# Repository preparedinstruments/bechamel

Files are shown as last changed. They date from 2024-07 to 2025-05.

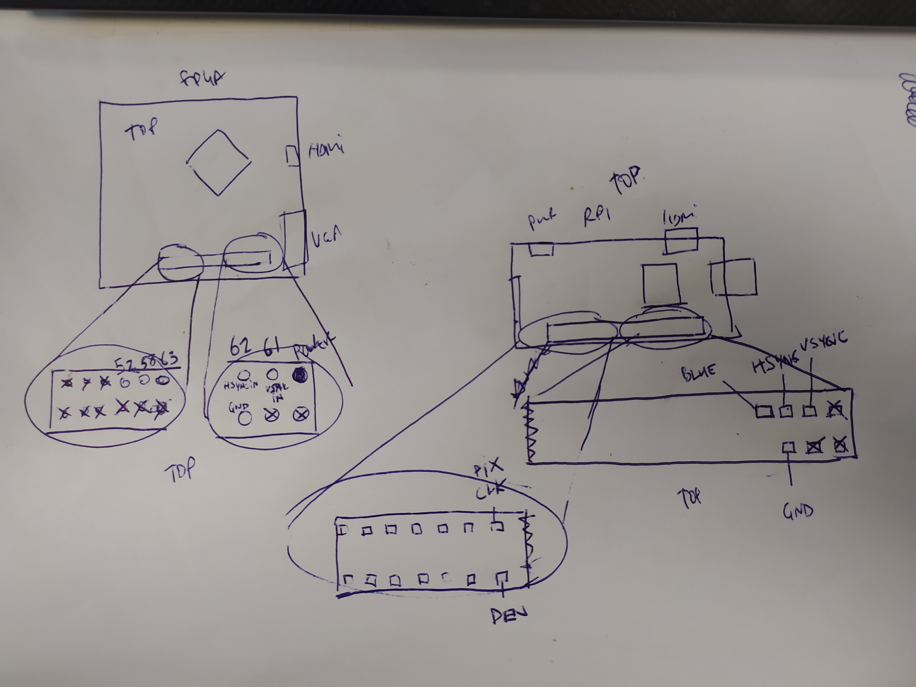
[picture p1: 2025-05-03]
verilog/SRAM FPGA RPI PASS THRU/IMG_20241218_101829.jpg

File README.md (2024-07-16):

bechamel_logo_Plan de travail 1

# Lo-Fi FPGA Video Art Board

A Lattice iCE40HX1K-based FPGA developement board for lo-fi, live-playable video experiments ranging from the gnarly/migraine-inducing all the way to the accidentally enjoyable.



 

|                          |                          |
:-------------------------:|:-------------------------:
  | IMG_3808-1024x683

# Features :

**WARNING: This video may potentially trigger seizures for people with photosensitive epilepsy. Viewer discretion is advised.**

https://github.com/user-attachments/assets/2b71dbfc-7b5e-4651-8198-416c93c0dd36

- 640x480 60Hz HDMI and VGA out, takes raspberry pi video in in DPI mode (https://pinout.xyz/pinout/dpi)
- 9-key mechanical button interface on a hand-solderable, low-cost, single-board design
- 100MHz clock and a 256K x 8 bit external SRAM for screen buffer(s)
- Connections for raspberry pi flash programming

# PCB files

[KiCAD and Eagle PCBs](https://github.com/preparedinstruments/bechamel/tree/main/PCB)

forgithub

# BOM :

[Excel BOM Mouser / Digikey ](https://github.com/preparedinstruments/bechamel/tree/main/BOM)

- 9x Mechanical keyboard keys
- 1x FPGA iCE40HX1K-TQ144
- 1x 100MHz clock oscillator
- 1x SRAM 2Mb 256Kx8
- 1x Flash N25Q032A13ESC40F
- 1x USB-C SMD 6 pin connector
- 1x 3.3V reg TLV73333PDBVT 
- 1x 1.2V reg TLV73312PDBVT
- 1x PFET
- 1x Resettable Fuse
- 1x D-SUB 15 connector
- 1x HDMI Connector 
- 50x 0.1µF capacitor 0805
- 50x  10kΩ, 1.8kΩ, 1kΩ, 470Ω, 270Ω, 120Ω resistors 0805
- 5x LEDs 0805
- 2x Dual-row headers

optional extras : (1x Raspberry Pi Zero, 1x Micro SD holder, 1x 10kΩ potentiometers)

# HDL files

[Verilog and Pin constraints files ](https://github.com/preparedinstruments/bechamel/tree/main/verilog)

To synthesize files :

[Yoysis Open-source Toolchain ](https://github.com/YosysHQ/yosys)



...or, request an iCEcube2 licence from Lattice :

[iCEcube2 Toolchain](https://www.latticesemi.com/iCEcube2)

To program flash memory you can use raspberry pi using these OLIMEX resources :

- https://www.olimex.com/wiki/ICE40HX1K-EVB#Get_started_under_Linux
- https://github.com/anse1/olimex-ice40-notes

# Raspberry Pi DPI config file

This config file sets the rpi in DPI mode at 50MHz. It can work with the rpi video pass thru verilog file.

[config.txt](https://github.com/preparedinstruments/bechamel/tree/main/raspberry_pi)

# FAQ

Q: How dare you release into the wild verilog code this hideous ?

A: Spank me daddy.

Q: Is this even art ?

A: I can't believe it's not butter! 

# Acknowledgements

**Verilog** :

Mike Field <hamster@snap.net.nz> for his minimalDVID_encoder.vhd : A quick and dirty DVI-D implementation (https://gist.github.com/uXeBoy/0d46e2f1560f73dd573d83e78309bfa0)

Iñigo Muguruza (imuguruza) for his VGA sync code : https://github.com/imuguruza/alhambra_II_test/blob/master/vga/vga_test/vga_sync.v

NightMachines on Bytebeats : https://llllllll.co/t/bytebeats-a-beginner-s-guide/16491

General verilog learning from HDL Bits : https://hdlbits.01xz.net/wiki/Main_Page

**FPGA Hardware design** :

OLIMEX FPGA dev board : https://github.com/OLIMEX/iCE40HX1K-EVB/tree/master

Alhambra II FPGA dev board : https://github.com/FPGAwars/Alhambra-II-FPGA/tree/master

# TODO

Get SD card reading functional

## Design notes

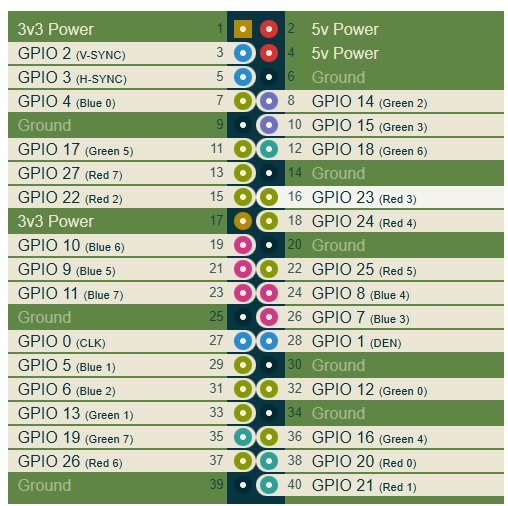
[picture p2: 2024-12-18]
verilog/SRAM FPGA RPI PASS THRU/rpi dpi pinout.PNG

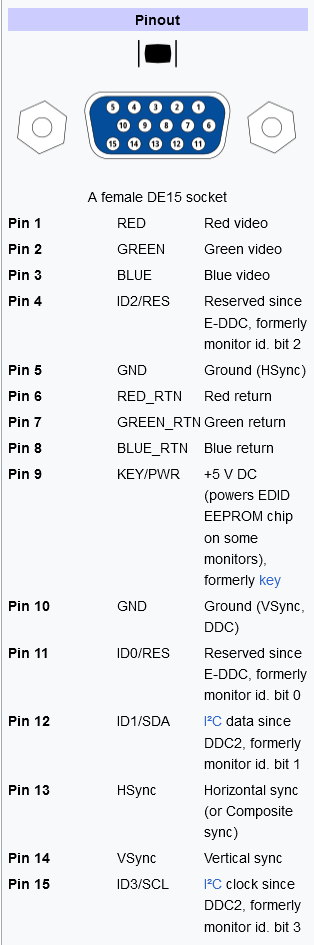
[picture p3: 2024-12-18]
verilog/SRAM FPGA RPI PASS THRU/VGA pinout.PNG

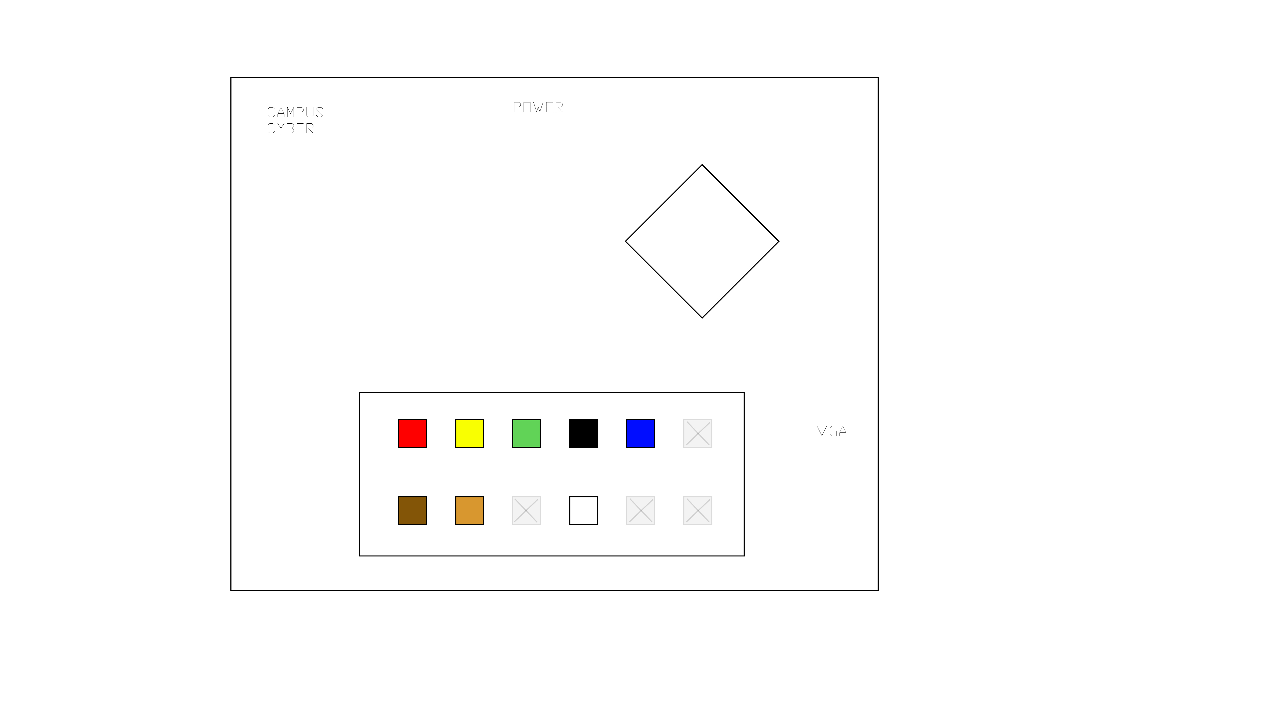
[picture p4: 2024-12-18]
verilog/SRAM FPGA RPI PASS THRU/PROGRAMMING HEADER FOR CAMPUS CYBER BOARD_Plan de travail 1.jpg

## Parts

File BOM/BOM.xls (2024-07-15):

Mouser No: | Mfr. No: | Desc.: | Order Qty.
71-CRCW0805180RJNEA | CRCW0805180RJNEA | Thick Film Resistors - SMD Thick Film Resistors - SMD 1/8watt 180ohms 5% | 15
603-AC0805FR-07100RL | AC0805FR-07100RL | Thick Film Resistors - SMD Thick Film Resistors - SMD 100 Ohms 125mW 0805 1% AEC-Q200 Standard Power Version | 15
80-C0805C104K8R | C0805C104K8RACTU | Multilayer Ceramic Capacitors MLCC - SMD/SMT Multilayer Ceramic Capacitors MLCC - SMD/SMT 10V 0.1uF X7R 0805 10% | 50
749-SM0805UOC | SM0805UOC | Standard LEDs - SMD Standard LEDs - SMD Ultra Orange 625 nm Water Clear | 1
710-150080GS75000 | 150080GS75000 | Standard LEDs - SMD Standard LEDs - SMD WL-SMCW SMDMono TpVw Waterclr 0805 Green | 1
156-3315-E | 156-3315-E | D-Sub High Density Connectors HD D-SUB PCB R/A FM GOLD FLASH 15P BLK | 1
649-1012938391201ALF | 10129383-912001ALF | Headers & Wire Housings Headers & Wire Housings ECONOSTIK HEADER DR VT SMT 2X6 | 1
621-BAS16HTWQ-13 | BAS16HTWQ-13 | Small Signal Switching Diodes Small Signal Switching Diodes Fast Switching Diode Array 100Vrm 75Vrrm | 1
179-UJC-HP2-3-SMT-TR | UJC-HP2-3-SMT-TR | USB Connectors USB Connectors | 1
842-ICE40HX1K-TQ144 | iCE40HX1K-TQ144 | FPGA - Field Programmable Gate Array FPGA - Field Programmable Gate Array iCE40HX 1280 LUTs 1.2V Ultra Low-Power | 1
913-N25Q032A13ESC40F | N25Q032A13ESC40F | NOR Flash NOR Flash Serial NOR Flash(MICRON), 32M, 3V, 108Mhz, Multiple IO, Industrial, 8pin SOIC Narrow, T&R | 1
530-SS-53000-001 | SS-53000-001 | HDMI, Displayport & DVI Connectors HDMI, Displayport & DVI Connectors HDMI RA W/Out Flange | 1
732-SG-818CA1MHPA3 | SG-8018CA 100.0000M-TJHPA3 | Standard Clock Oscillators Standard Clock Oscillators SG-8018CA 100.0000M-TJHPA3: MHZ OSC 1.8V~3.3V +/-50PPM -40~105C O/E 250TR | 1
603-SMD0805B110TF | SMD0805B110TF | Resettable Fuses - PPTC Resettable Fuses - PPTC 6V 1.1A PPTC SMD 0805 | 1
771-BSS84AK215 | BSS84AK,215 | MOSFETs MOSFETs BSS84AK/SOT23/TO-236AB | 1
708-RNCP0805FTD10K0 | RNCP0805FTD10K0 | Thin Film Resistors - SMD Thin Film Resistors - SMD 10KOhms 0805 0.25W 100ppm 1% Hi Pwr Anti-Sulfur | 50
603-AC0805FR-7W1KL | AC0805FR-7W1KL | Thick Film Resistors - SMD Thick Film Resistors - SMD 1 kOhms 250mW 0805 1 % AEC-Q200 Double Power Version | 25
603-RC0805JR-07270RL | RC0805JR-07270RL | Thick Film Resistors - SMD Thick Film Resistors - SMD 270 Ohms 125 mW 0805 5% | 10
667-ERJ-6GEYJ121V | ERJ-6GEYJ121V | Thick Film Resistors - SMD Thick Film Resistors - SMD 0805 120ohms 5% AEC-Q200 | 10
279-CRG0805J470R | CRG0805J470R | Thick Film Resistors - SMD Thick Film Resistors - SMD CRG0805 5% 470R | 10
756-WCR0805-1K8FI | WCR0805-1K8FI | Thick Film Resistors - SMD Thick Film Resistors - SMD 1.8K ohm 1% 150V General Purpose SMT | 10
652-CR0805JW-512ELF | CR0805-JW-512ELF | Thick Film Resistors - SMD Thick Film Resistors - SMD 5.1K 5% | 1
603-RT0805FRE071ML | RT0805FRE071ML | Thin Film Resistors - SMD Thin Film Resistors - SMD 1/8W 1M ohm 1% 50ppm | 1
595-TLV73333PDBVT | TLV73333PDBVT | LDO Voltage Regulators Cap-Free,300mA,LDO Reg | 1
595-TLV73312PDBVT | TLV73312PDBVT | LDO Voltage Regulators Cap-Free,300mA,LDO Reg | 1
798-DM3CSSF | DM3CS-SF | Memory Card Connectors 8P R/A SMT MICRO SD HINGE PUSH-PULL | 1
312-1001F-10K | RV100F-30-4K1B-B10K-B301 | Potentiometers 10mm Linear 10K PC Mount | 1
485-2243 | 2243 | Raspberry Pi Hats / Add-on Boards GPIO Header for Raspberry Pi HAT - 2x20 Short Female Header | 1
87062WV2568BLL55HLI | IS62WV2568BLL-55HLI | SRAM 2Mb 256Kx8 55ns Async SRAM | 1
540-MX1A-11NW | MX1A-11NW | Pushbutton Switches Full Travel, Mech. KeyswitchLinear Feel, 60cNNo LED, No DiodeFixation Pins for PCB Mounting | 9

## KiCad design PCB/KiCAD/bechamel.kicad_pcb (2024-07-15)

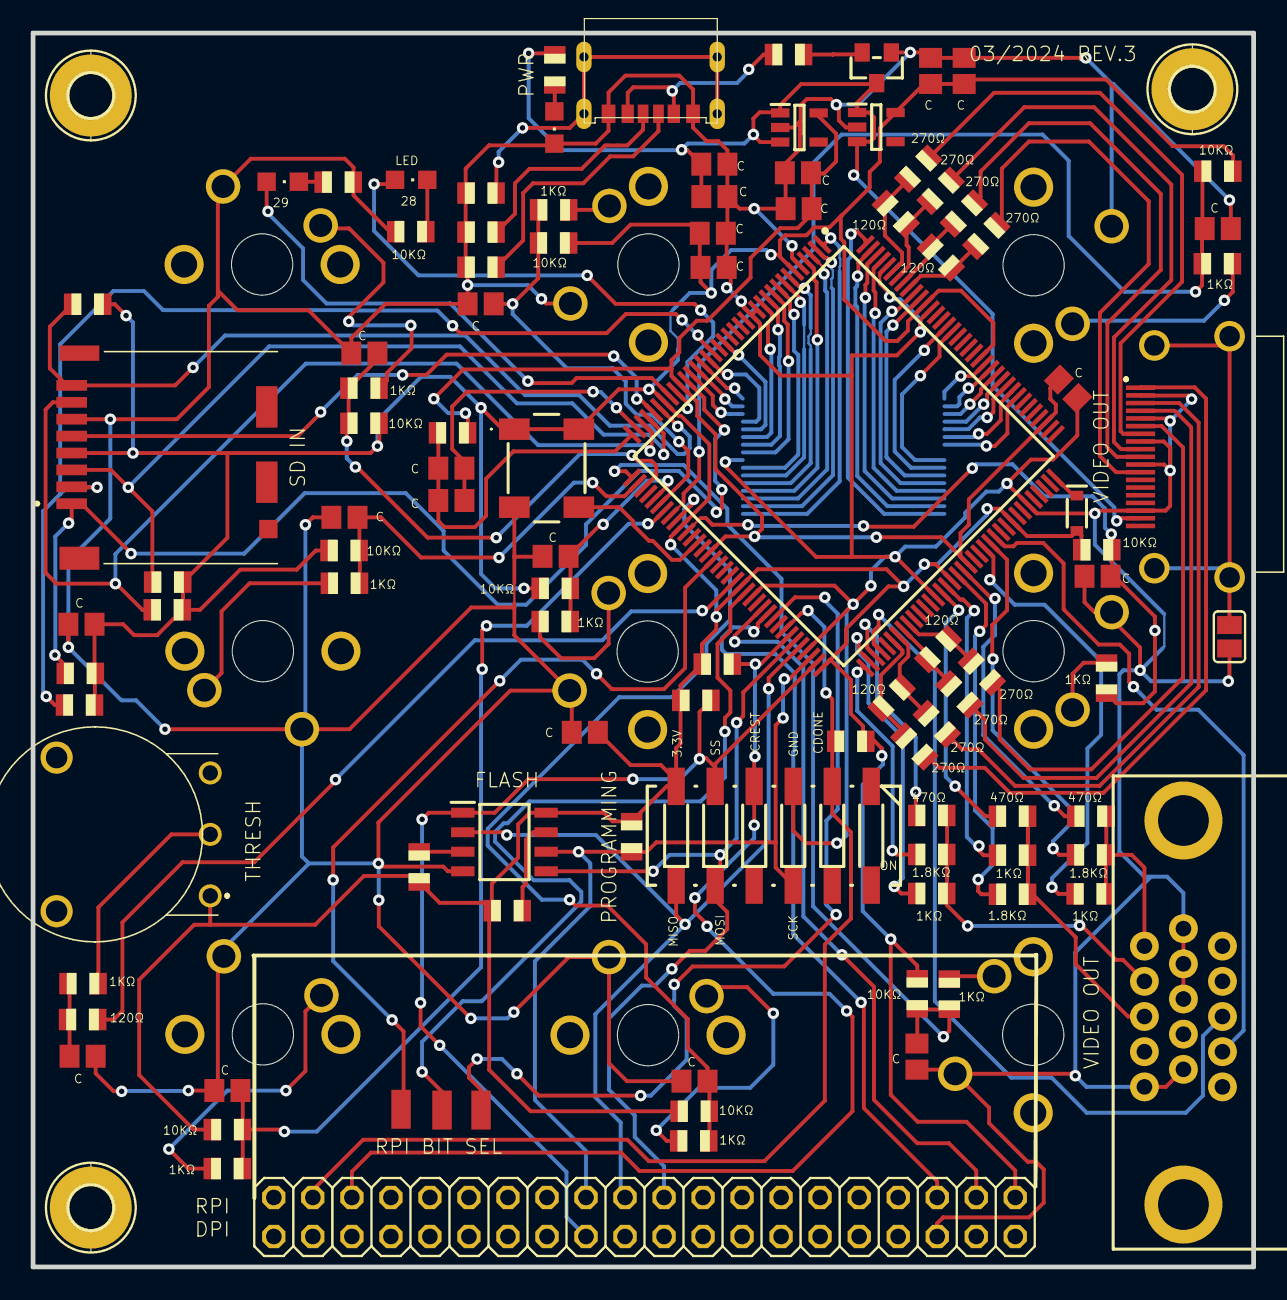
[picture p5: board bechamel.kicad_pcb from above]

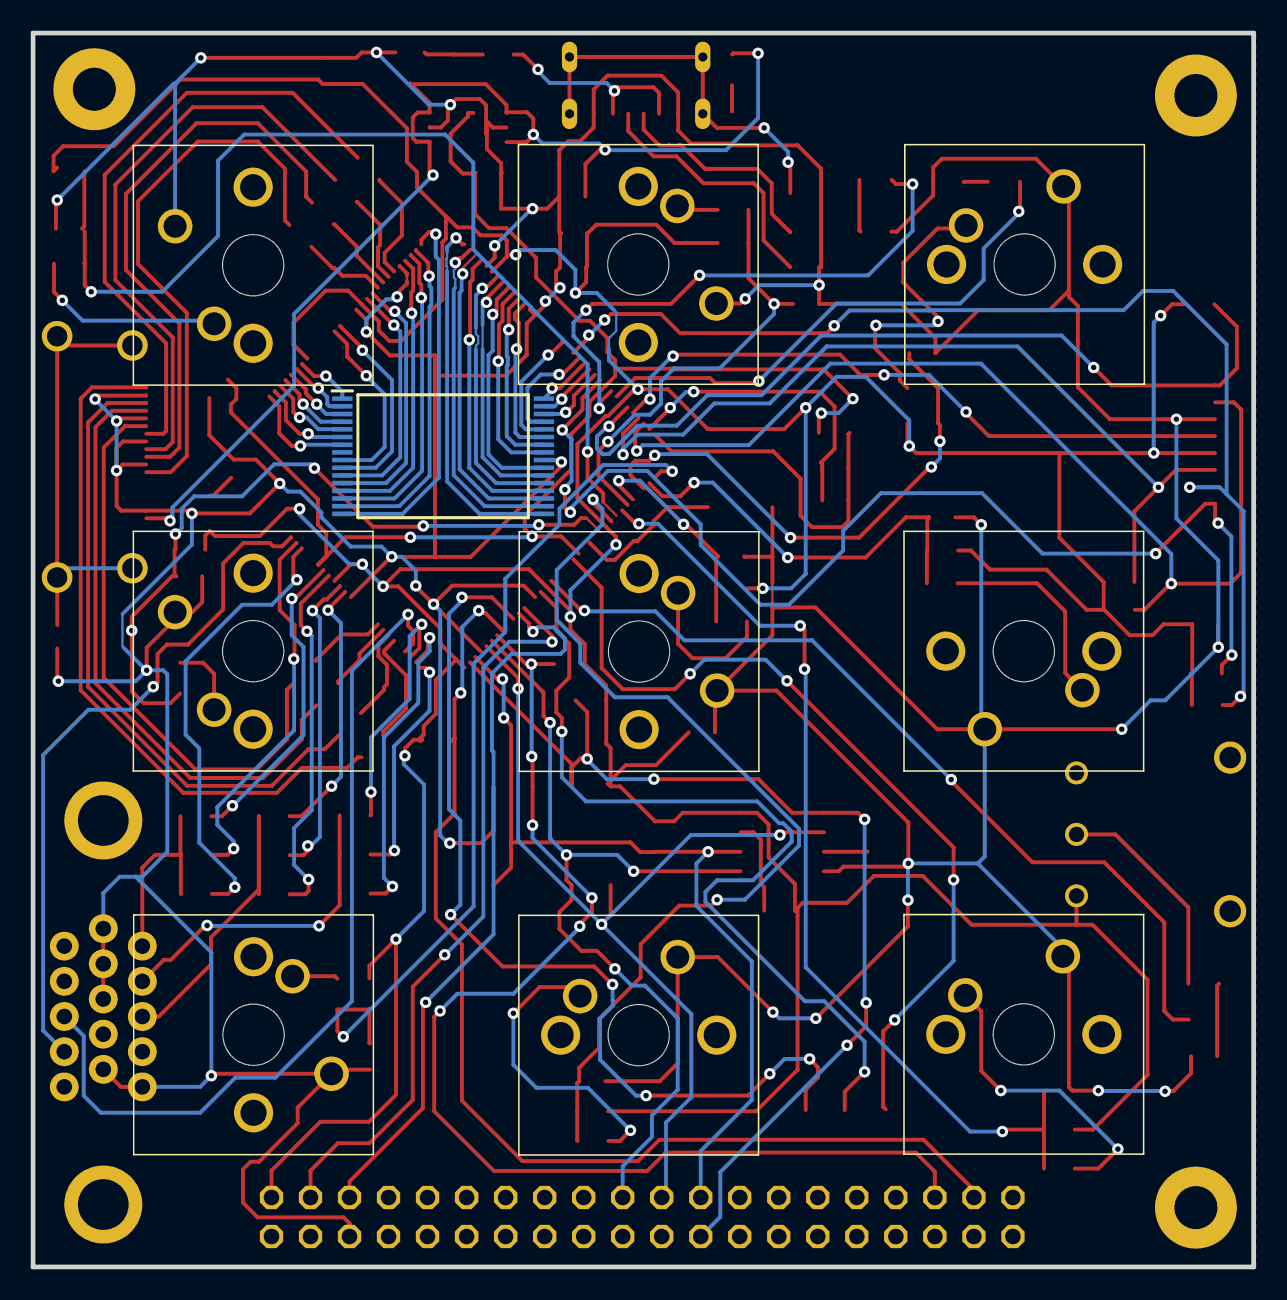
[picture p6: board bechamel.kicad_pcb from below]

Board: 2 copper layers, 79.5 x 80.3 mm, 117 parts (10 on the bottom side), 119 nets.

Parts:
C1, C6, C7, C8, C9, C10, C11, C12, C13, C14, C15, C18, C21, C22, C25, C26, C27: 0.1uF; C0805
C3, C4, C5, C16, C23: 10uF; C0805
C17: 5.6nF; C0805
D1: 250mA/100V; SOD-323
FUSE0: FUSE; R0805
H1, H5, H6: MOUNT-PAD-ROUND2.8; 2,8-PAD
IC1: TLV73333PDBVT; SOT95P280X145-5N
IC2: ICE40HX1K-TQ144; QFP50P2200X2200X160-144N
IC3: TLV73312PDBVT; SOT95P280X145-5N
IC4: N25Q032A13ESC40F; SOIC127P600X175-8N
IC6: IS62WV2568BLL-55HLI; SOP50P1340X125-32N
J2: SS-53000-001; SS53000001
J3: DM3CS-SF; DM3CSSF
JP1: 2X20
LED6, LED12, LED13: CHIPLED_0805
P-FET2: SOT23-WIDE
PAD1, PAD2, PAD3: SMD1,27-2,54
R1, R17, R25: 470R; R0805
R2, R5, R7, R15, R18, R22, R24, R26, R47, R49, R51, R53: 1K; R0805
R3, R4, R6, R8, R9, R10, R11, R12, R13, R21, R23, R45, R46, R48, R50, R52, R54, R55, R58, R59: 10K; R0805
R14, R36, R37: 100 ohm; R0805
R16, R20, R27: 1.8K; R0805
R19: 300 ohm; R0805
R28, R29, R31, R32, R34, R35, R39, R40: 270R; R0805
R30, R33, R38, R41: 120R; R0805
R42: 1M; R0805
R43, R44: 5k1; R0805
R56: 1K8 ohm; R0805
R57: 180 ohm; R0805
S1, S2, S3, S4, S5, S6, S7, S8, S13: MX1A-11NW; MX1A11NW
S9: 219-06J; CTS-219-06J
SJ2: SJ
U$1: DB15
U$2: USBC-6P; USCX-06FX-XXMX-01
VR1: RV100F-30-4K1B-B10K-B301; RV100F304K1BB10KB301
Y2: ECS-3953M-080-BN-T-TR; ECS3953M080BNTTR

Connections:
1.2V: C4.1, C26.1, C27.1, IC2.27, IC2.51, IC2.92, IC2.111, IC3.5, R14.2
3.3V: C12.1, C15.1, C16.2, C18.1, C21.1, C25.1, D1.A, IC1.5, IC2.6, IC2.30, IC2.46, IC2.57, IC2.72, IC2.89, IC2.100, IC2.123, IC2.133, IC4.8, J3.4, JP1.1, R3.2, R4.2, R6.2, R8.2, R9.2, R10.2, R11.2, R12.2, R13.2, R21.2, R23.2, R45.2, R46.2, R48.2, R50.2, R52.2, R54.2, R55.1, R58.2, R59.2, S9.6, VR1.1, Y2.1, Y2.4
5V: C3.1, C5.1, IC1.1, IC1.3, IC3.1, IC3.3, J2.18, P-FET2.3, R19.2
5V?: FUSE0.1, P-FET2.2
A0: IC2.4, IC6.20
A1: IC2.3, IC6.19
A2: IC2.2, IC6.18
A3: IC2.1, IC6.17
A4: IC2.144, IC6.16
A5: IC2.143, IC6.15
A6: IC2.142, IC6.14
A7: IC2.141, IC6.13
A8: IC2.120, IC6.3
A9: IC2.121, IC6.2
A10: IC2.24, IC6.31
A11: IC2.122, IC6.1
A12: IC2.135, IC6.12
A13: IC2.119, IC6.4
A14: IC2.134, IC6.11
A15: IC2.116, IC6.7
A16: IC2.129, IC6.10
A17: IC2.128, IC6.9
ADC_IN: IC2.56, R57.2
BLUE: R1.2, R15.2, R16.2, U$1.3
BLUE_1: IC2.87, R1.1
BLUE_2: IC2.88, R15.1
BLUE_3: IC2.90, R16.1
CLK+: IC2.137, R39.2, R41.1
CLK-: IC2.136, R40.2, R41.2
CMD: IC2.33, J3.3, R54.1
CS2: IC2.117, IC6.6
DAT0: IC2.34, J3.7, R55.2
DAT1: IC2.31, J3.8, R59.1
DAT2: IC2.26, J3.1, R45.1
DAT3: IC2.21, J3.2, R58.1
DATA0+: IC2.139, R34.2, R38.1
DATA0-: IC2.138, R35.2, R38.2
DATA1+: IC2.80, R31.2, R33.1
DATA1-: IC2.81, R32.2, R33.2
DATA2+: IC2.78, R28.2, R30.1
DATA2-: IC2.79, R29.2, R30.2
FPGA_CLK: IC2.49, Y2.3
GND: C1.1, C3.2, C4.2, C5.2, C6.1, C7.1, C8.1, C9.1, C10.1, C11.1, C12.2, C13.1, C14.1, C15.2, C16.1, C17.1, C18.2, C21.2, C25.2, C26.2, C27.2, IC1.2, IC2.5, IC2.13, IC2.14, IC2.59, IC2.69, IC2.86, IC2.103, IC2.132, IC2.140, IC3.2, IC4.4, IC6.24, J2.2, J2.5, J2.8, J2.11, J2.17, J3.6, JP1.6, LED6.C, P-FET2.1, R36.1, R37.1, R42.2, R43.2, R44.2, S1.2, S2.2, S3.2, S4.2, S5.2, S6.2, S7.2, S8.2, S9.3, S13.2, SJ2.2, U$1.5, U$1.6, U$1.7, U$1.8, U$1.10, U$2.GND1, U$2.GND2, Y2.2
GREEN: R17.2, R18.2, R20.2, U$1.2
GREEN_1: IC2.75, R17.1
GREEN_2: IC2.74, R18.1
GREEN_3: IC2.73, R20.1
H_SYNC: IC2.76, U$1.13
H_SYNC_IN: IC2.62, JP1.5
I/O0: IC2.7, IC6.21
I/O1: IC2.8, IC6.22
I/O2: IC2.9, IC6.23
I/O3: IC2.10, IC6.25
I/O4: IC2.11, IC6.26
I/O5: IC2.12, IC6.27
I/O6: IC2.19, IC6.28
I/O7: IC2.22, IC6.29
ICE_CDONE: IC2.65, JP1.37, R8.1, S9.2
ICE_CREST: IC2.66, JP1.35, R9.1, S9.4
ICE_MISO: IC2.68, IC4.2, JP1.21, S9.7
ICE_MOSI: IC2.67, IC4.5, JP1.19, S9.8
ICE_SCK: IC2.70, IC4.6, JP1.23, R13.1, S9.10
ICE_SS_B: IC2.71, IC4.1, JP1.24, R12.1, S9.5
KEY_0: C13.2, IC2.37, R50.1, R51.2
KEY_0_LED: IC2.28, LED12.A
KEY_1: C6.2, IC2.38, R3.1, R5.2
KEY_1_LED: IC2.29, LED13.A
KEY_2: C11.2, IC2.39, R48.1, R49.2
KEY_3: C1.2, IC2.41, R2.2, R4.1
KEY_4: C10.2, IC2.42, R46.1, R47.2
KEY_5: C7.2, IC2.43, R6.1, R7.2
KEY_6: C9.2, IC2.44, R23.1, R24.2
KEY_7: C8.2, IC2.45, R21.1, R22.2
KEY_8: C14.2, IC2.47, R52.1, R53.2
unnamed: IC4.7, R10.1
unnamed: LED6.A, R19.1
unnamed: IC4.3, R11.1
unnamed: R43.1, U$2.CC2
unnamed: D1.C, IC2.108
unnamed: C22.2, C23.2, IC2.35
unnamed: C22.1, C23.1, IC2.36, R14.1
unnamed: R42.1, U$2.SHIELD1, U$2.SHIELD2, U$2.SHIELD3, U$2.SHIELD4
unnamed: R56.2, VR1.2
unnamed: J2.1, R28.1
unnamed: R44.1, U$2.CC1
unnamed: J2.MH1, J2.MH2, J2.MH3, J2.MH4, SJ2.1
unnamed: C17.2, R56.1, R57.1
unnamed: J2.3, R29.1
unnamed: J2.4, R31.1
unnamed: LED12.C, R36.2
unnamed: LED13.C, R37.2
unnamed: J2.6, R32.1
unnamed: IC2.52, PAD1.1
unnamed: J2.7, R34.1
unnamed: J2.9, R35.1
unnamed: J2.10, R39.1
unnamed: J2.12, R40.1
unnamed: R2.1, S6.1
unnamed: R5.1, S5.1
unnamed: R7.1, S7.1
unnamed: R22.1, S8.1
unnamed: R24.1, S3.1
unnamed: R47.1, S2.1
unnamed: R49.1, S1.1
unnamed: R51.1, S13.1
unnamed: R53.1, S4.1
unnamed: IC2.58, PAD2.1
unnamed: IC2.63, PAD3.1
PRE_FUSE: FUSE0.2, U$2.VBUS1, U$2.VBUS2
RED: R25.2, R26.2, R27.2, U$1.1
RED_1: IC2.91, R25.1
RED_2: IC2.95, R26.1
RED_3: IC2.96, R27.1
SD_CLK: IC2.32, J3.5
V_SYNC: IC2.97, U$1.14
V_SYNC_IN: IC2.61, JP1.3
~CS1: IC2.25, IC6.30
~OE: IC2.23, IC6.32
~WE: IC2.118, IC6.5

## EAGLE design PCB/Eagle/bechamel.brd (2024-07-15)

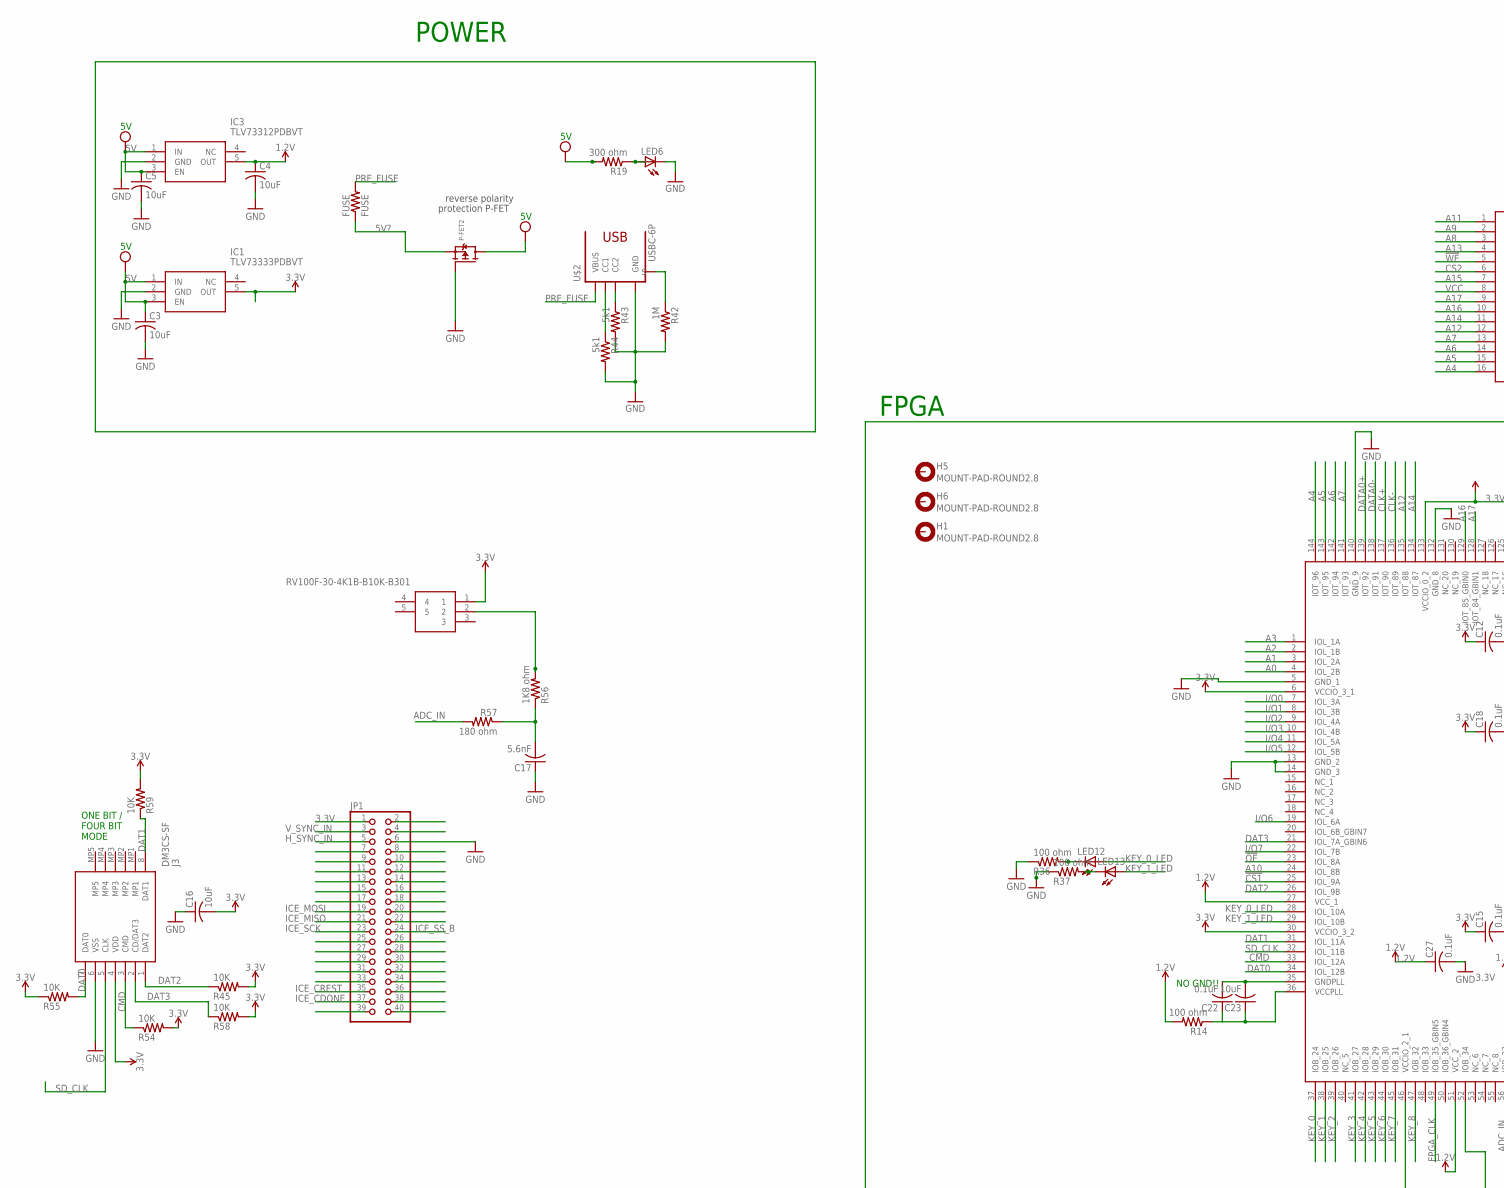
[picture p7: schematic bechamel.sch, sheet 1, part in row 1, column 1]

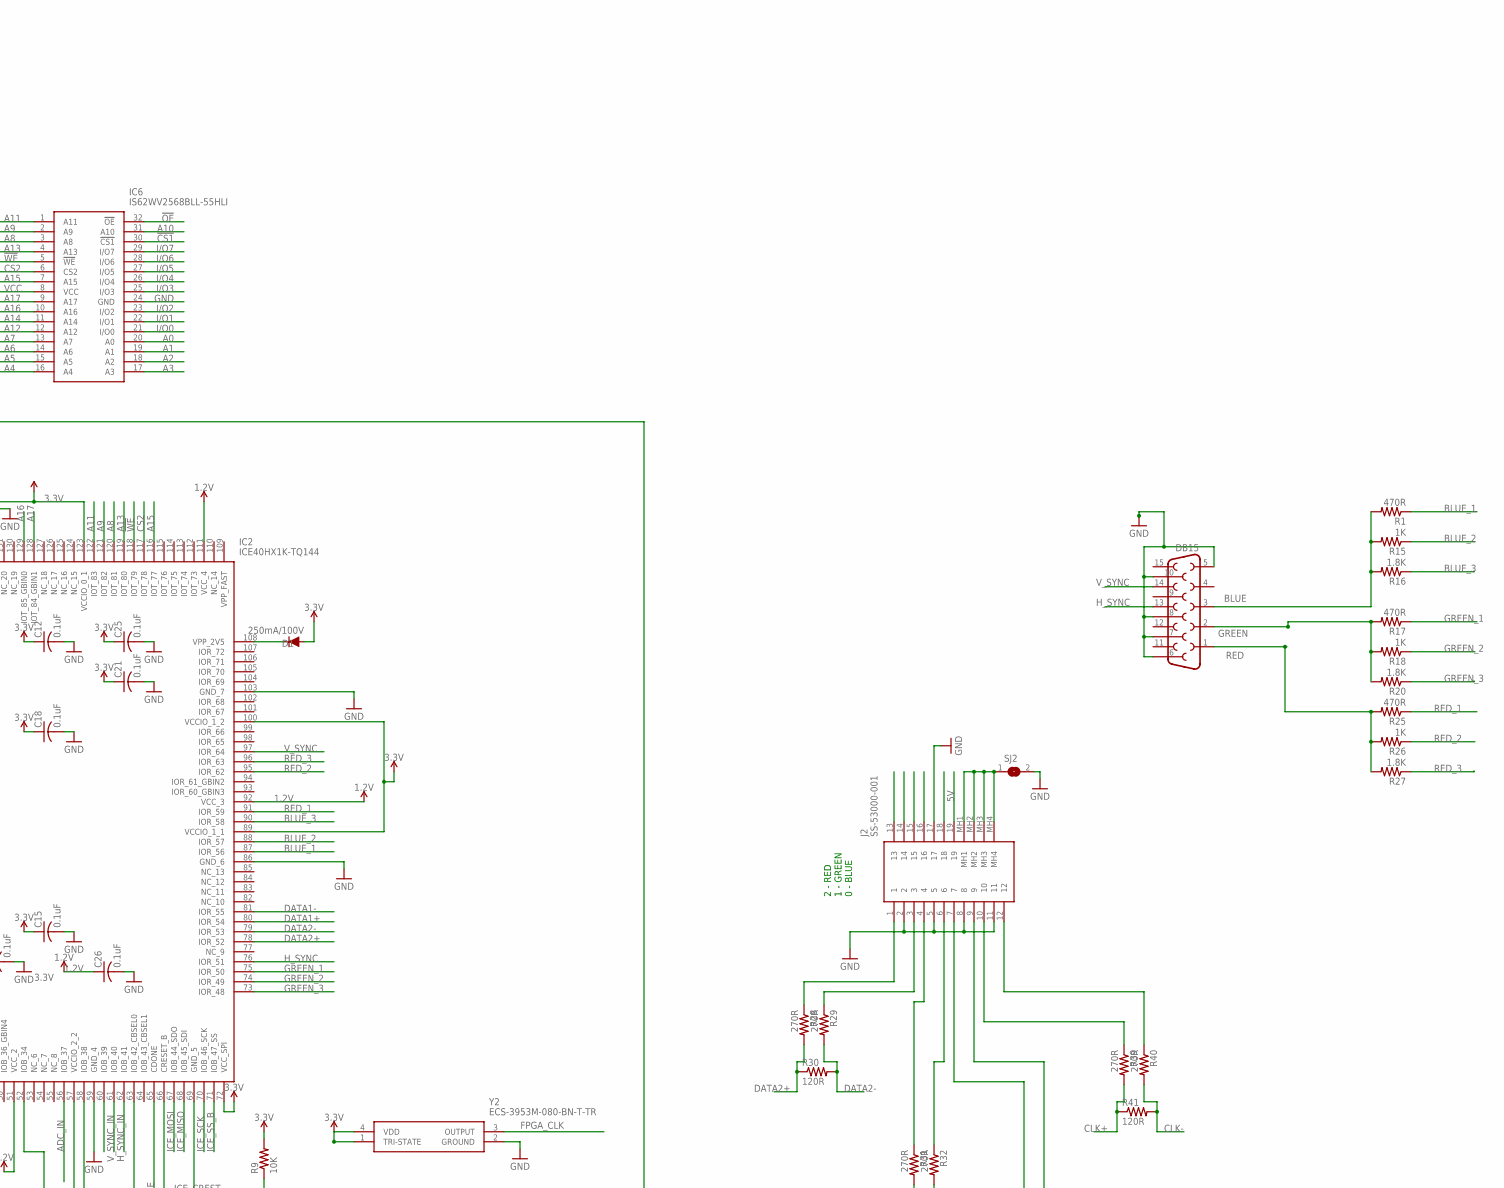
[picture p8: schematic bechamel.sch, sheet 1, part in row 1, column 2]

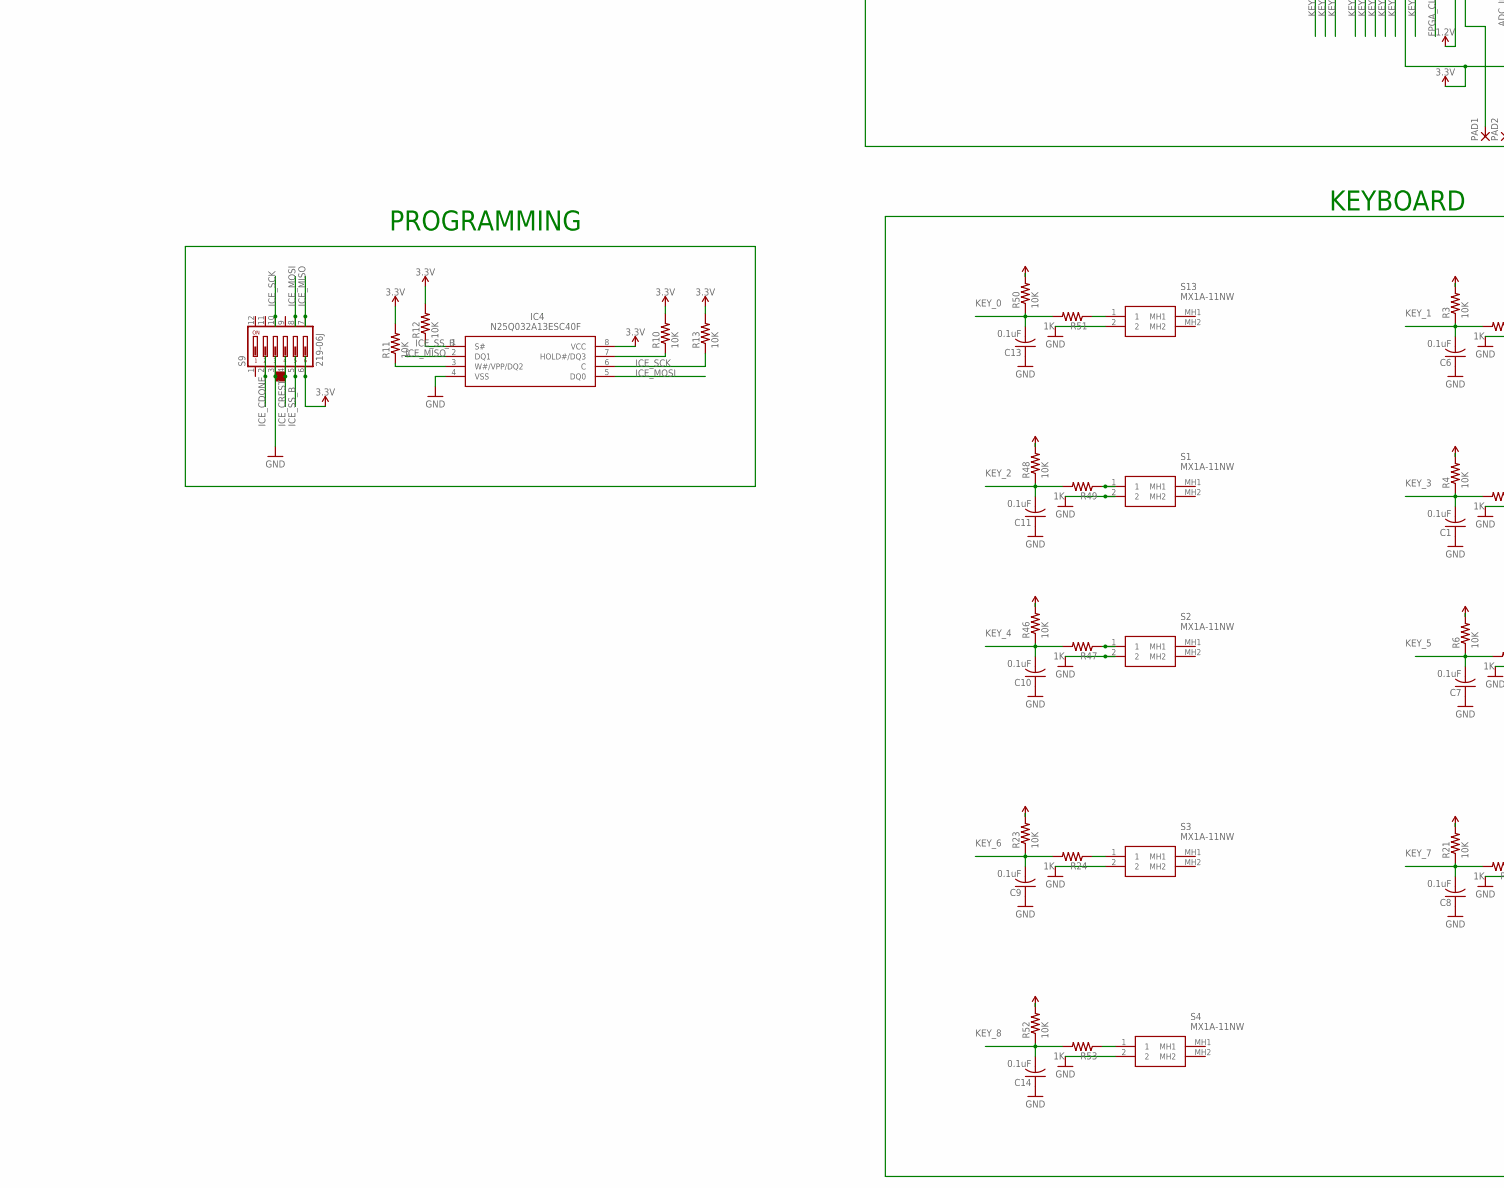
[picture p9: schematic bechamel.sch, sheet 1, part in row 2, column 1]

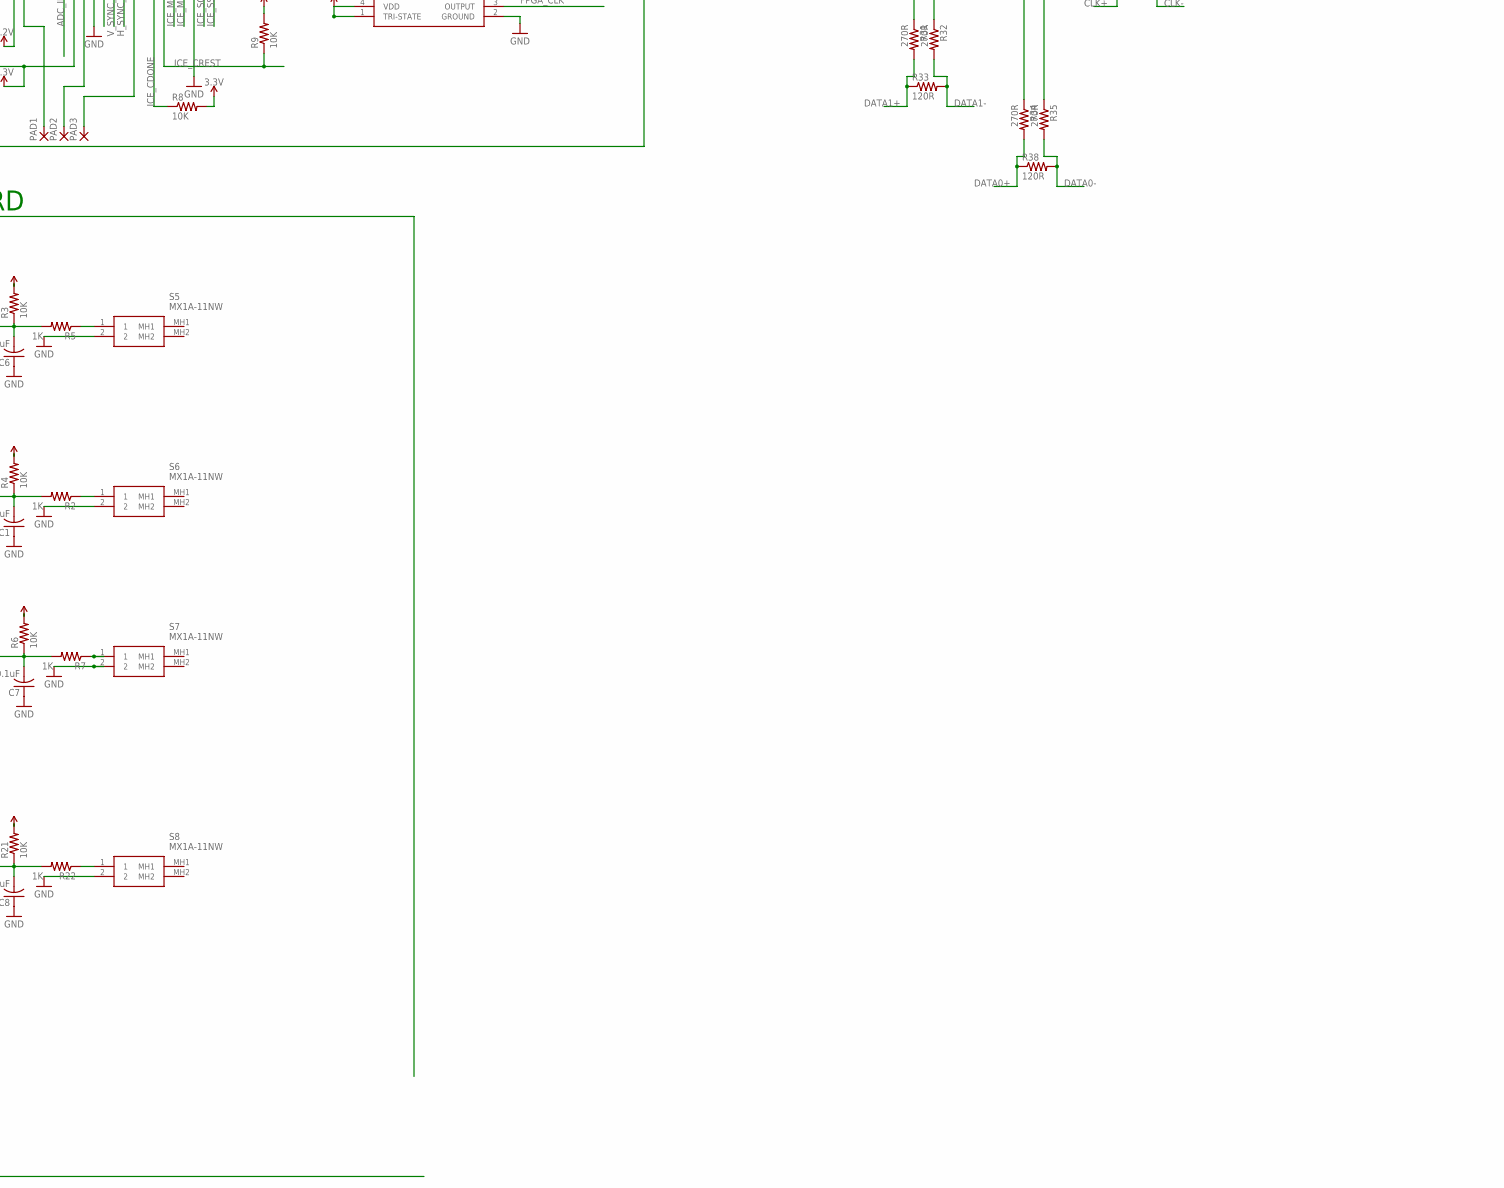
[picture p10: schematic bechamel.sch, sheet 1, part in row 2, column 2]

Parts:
C1, C6, C7, C8, C9, C10, C11, C12, C13, C14, C15, C18, C21, C22, C25, C26, C27: 0.1uF; C0805
C3, C4, C5, C16, C23: 10uF; C0805
C17: 5.6nF; C0805
D1: 250mA/100V; SOD-323
FUSE: FUSE; R0805
H1, H5, H6: MOUNT-PAD-ROUND2.8; 2,8-PAD
IC1: TLV73333PDBVT; SOT95P280X145-5N
IC2: ICE40HX1K-TQ144; QFP50P2200X2200X160-144N
IC3: TLV73312PDBVT; SOT95P280X145-5N
IC4: N25Q032A13ESC40F; SOIC127P600X175-8N
IC6: IS62WV2568BLL-55HLI; SOP50P1340X125-32N
J2: SS-53000-001; SS53000001
J3: DM3CS-SF; DM3CSSF
JP1: PINHD-2X20; 2X20
LED6, LED12, LED13: LEDCHIPLED_0805; CHIPLED_0805
P-FET2: MOSFET-PWIDE; SOT23-WIDE
PAD1, PAD2, PAD3: SMD2; SMD1,27-2,54
R1, R17, R25: 470R; R0805
R2, R5, R7, R15, R18, R22, R24, R26, R47, R49, R51, R53: 1K; R0805
R3, R4, R6, R8, R9, R10, R11, R12, R13, R21, R23, R45, R46, R48, R50, R52, R54, R55, R58, R59: 10K; R0805
R14, R36, R37: 100 ohm; R0805
R16, R20, R27: 1.8K; R0805
R19: 300 ohm; R0805
R28, R29, R31, R32, R34, R35, R39, R40: 270R; R0805
R30, R33, R38, R41: 120R; R0805
R42: 1M; R0805
R43, R44: 5k1; R0805
R56: 1K8 ohm; R0805
R57: 180 ohm; R0805
S1, S2, S3, S4, S5, S6, S7, S8, S13: MX1A-11NW; MX1A11NW
S9: 219-06J; CTS-219-06J
SJ2: SJ
U$1: DB15
U$2: USBC-6P; USCX-06FX-XXMX-01
VR1: RV100F-30-4K1B-B10K-B301; RV100F304K1BB10KB301
Y2: ECS-3953M-080-BN-T-TR; ECS3953M080BNTTR

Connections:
1.2V: C4.1, C26.1, C27.1, IC2.27 (VCC_1), IC2.51 (VCC_2), IC2.92 (VCC_3), IC2.111 (VCC_4), IC3.5 (OUT), R14.2
3.3V: C12.1, C15.1, C16.2, C18.1, C21.1, C25.1, D1.A, IC1.5 (OUT), IC2.6 (VCCIO_3_1), IC2.30 (VCCIO_3_2), IC2.46 (VCCIO_2_1), IC2.57 (VCCIO_2_2), IC2.72 (VCC_SPI), IC2.89 (VCCIO_1_1), IC2.100 (VCCIO_1_2), IC2.123 (VCCIO_0_1), IC2.133 (VCCIO_0_2), IC4.8 (VCC), J3.4 (VDD), JP1.1, R3.2, R4.2, R6.2, R8.2, R9.2, R10.2, R11.2, R12.2, R13.2, R21.2, R23.2, R45.2, R46.2, R48.2, R50.2, R52.2, R54.2, R55.1, R58.2, R59.2, S9.6, VR1.1, Y2.1 (TRI-STATE), Y2.4 (VDD)
5V: C3.1, C5.1, IC1.1 (IN), IC1.3 (EN), IC3.1 (IN), IC3.3 (EN), J2.18, P-FET2.3 (D), R19.2
5V?: FUSE.1, P-FET2.2 (S)
!CS1: IC2.25 (IOL_9A), IC6.30 (!CS1)
!OE: IC2.23 (IOL_8A), IC6.32 (!OE)
!WE: IC2.118 (IOT_79), IC6.5 (!WE)
A0: IC2.4 (IOL_2B), IC6.20 (A0)
A1: IC2.3 (IOL_2A), IC6.19 (A1)
A2: IC2.2 (IOL_1B), IC6.18 (A2)
A3: IC2.1 (IOL_1A), IC6.17 (A3)
A4: IC2.144 (IOT_96), IC6.16 (A4)
A5: IC2.143 (IOT_95), IC6.15 (A5)
A6: IC2.142 (IOT_94), IC6.14 (A6)
A7: IC2.141 (IOT_93), IC6.13 (A7)
A8: IC2.120 (IOT_81), IC6.3 (A8)
A9: IC2.121 (IOT_82), IC6.2 (A9)
A10: IC2.24 (IOL_8B), IC6.31 (A10)
A11: IC2.122 (IOT_83), IC6.1 (A11)
A12: IC2.135 (IOT_88), IC6.12 (A12)
A13: IC2.119 (IOT_80), IC6.4 (A13)
A14: IC2.134 (IOT_87), IC6.11 (A14)
A15: IC2.116 (IOT_77), IC6.7 (A15)
A16: IC2.129 (IOT_85_GBIN0), IC6.10 (A16)
A17: IC2.128 (IOT_84_GBIN1), IC6.9 (A17)
ADC_IN: IC2.56 (IOB_37), R57.2
BLUE: R1.2, R15.2, R16.2, U$1.3
BLUE_1: IC2.87 (IOR_56), R1.1
BLUE_2: IC2.88 (IOR_57), R15.1
BLUE_3: IC2.90 (IOR_58), R16.1
CLK+: IC2.137 (IOT_90), R39.2, R41.1
CLK-: IC2.136 (IOT_89), R40.2, R41.2
CMD: IC2.33 (IOL_12A), J3.3 (CMD), R54.1
CS2: IC2.117 (IOT_78), IC6.6 (CS2)
DAT0: IC2.34 (IOL_12B), J3.7 (DAT0), R55.2
DAT1: IC2.31 (IOL_11A), J3.8 (DAT1), R59.1
DAT2: IC2.26 (IOL_9B), J3.1 (DAT2), R45.1
DAT3: IC2.21 (IOL_7A_GBIN6), J3.2 (CD/DAT3), R58.1
DATA0+: IC2.139 (IOT_92), R34.2, R38.1
DATA0-: IC2.138 (IOT_91), R35.2, R38.2
DATA1+: IC2.80 (IOR_54), R31.2, R33.1
DATA1-: IC2.81 (IOR_55), R32.2, R33.2
DATA2+: IC2.78 (IOR_52), R28.2, R30.1
DATA2-: IC2.79 (IOR_53), R29.2, R30.2
FPGA_CLK: IC2.49 (IOB_35_GBIN5), Y2.3 (OUTPUT)
GND: C1.1, C3.2, C4.2, C5.2, C6.1, C7.1, C8.1, C9.1, C10.1, C11.1, C12.2, C13.1, C14.1, C15.2, C16.1, C17.1, C18.2, C21.2, C25.2, C26.2, C27.2, IC1.2 (GND), IC2.5 (GND_1), IC2.13 (GND_2), IC2.14 (GND_3), IC2.59 (GND_4), IC2.69 (GND_5), IC2.86 (GND_6), IC2.103 (GND_7), IC2.132 (GND_8), IC2.140 (GND_9), IC3.2 (GND), IC4.4 (VSS), IC6.24 (GND), J2.2, J2.5, J2.8, J2.11, J2.17, J3.6 (VSS), JP1.6, LED6.C, P-FET2.1 (G), R36.1, R37.1, R42.2, R43.2, R44.2, S1.2, S2.2, S3.2, S4.2, S5.2, S6.2, S7.2, S8.2, S9.3, S13.2, SJ2.2, U$1.5, U$1.6, U$1.7, U$1.8, U$1.10, U$2.GND1 (GND), U$2.GND2 (GND), Y2.2 (GROUND)
GREEN: R17.2, R18.2, R20.2, U$1.2
GREEN_1: IC2.75 (IOR_50), R17.1
GREEN_2: IC2.74 (IOR_49), R18.1
GREEN_3: IC2.73 (IOR_48), R20.1
H_SYNC: IC2.76 (IOR_51), U$1.13
H_SYNC_IN: IC2.62 (IOB_41), JP1.5
I/O0: IC2.7 (IOL_3A), IC6.21 (I/O0)
I/O1: IC2.8 (IOL_3B), IC6.22 (I/O1)
I/O2: IC2.9 (IOL_4A), IC6.23 (I/O2)
I/O3: IC2.10 (IOL_4B), IC6.25 (I/O3)
I/O4: IC2.11 (IOL_5A), IC6.26 (I/O4)
I/O5: IC2.12 (IOL_5B), IC6.27 (I/O5)
I/O6: IC2.19 (IOL_6A), IC6.28 (I/O6)
I/O7: IC2.22 (IOL_7B), IC6.29 (I/O7)
ICE_CDONE: IC2.65 (CDONE), JP1.37, R8.1, S9.2
ICE_CREST: IC2.66 (CRESET_B), JP1.35, R9.1, S9.4
ICE_MISO: IC2.68 (IOB_45_SDI), IC4.2 (DQ1), JP1.21, S9.7
ICE_MOSI: IC2.67 (IOB_44_SDO), IC4.5 (DQ0), JP1.19, S9.8
ICE_SCK: IC2.70 (IOB_46_SCK), IC4.6 (C), JP1.23, R13.1, S9.10
ICE_SS_B: IC2.71 (IOB_47_SS), IC4.1 (S#), JP1.24, R12.1, S9.5
KEY_0: C13.2, IC2.37 (IOB_24), R50.1, R51.2
KEY_0_LED: IC2.28 (IOL_10A), LED12.A
KEY_1: C6.2, IC2.38 (IOB_25), R3.1, R5.2
KEY_1_LED: IC2.29 (IOL_10B), LED13.A
KEY_2: C11.2, IC2.39 (IOB_26), R48.1, R49.2
KEY_3: C1.2, IC2.41 (IOB_27), R2.2, R4.1
KEY_4: C10.2, IC2.42 (IOB_28), R46.1, R47.2
KEY_5: C7.2, IC2.43 (IOB_29), R6.1, R7.2
KEY_6: C9.2, IC2.44 (IOB_30), R23.1, R24.2
KEY_7: C8.2, IC2.45 (IOB_31), R21.1, R22.2
KEY_8: C14.2, IC2.47 (IOB_32), R52.1, R53.2
unnamed: IC4.7 (HOLD#/DQ3), R10.1
unnamed: LED6.A, R19.1
unnamed: IC4.3 (W#/VPP/DQ2), R11.1
unnamed: R43.1, U$2.CC2
unnamed: D1.C, IC2.108 (VPP_2V5)
unnamed: C22.2, C23.2, IC2.35 (GNDPLL)
unnamed: C22.1, C23.1, IC2.36 (VCCPLL), R14.1
unnamed: R42.1, U$2.SHIELD1 (S), U$2.SHIELD2 (S), U$2.SHIELD3 (S), U$2.SHIELD4 (S)
unnamed: R56.2, VR1.2
unnamed: J2.1, R28.1
unnamed: R44.1, U$2.CC1
unnamed: J2.MH1, J2.MH2, J2.MH3, J2.MH4, SJ2.1
unnamed: C17.2, R56.1, R57.1
unnamed: J2.3, R29.1
unnamed: J2.4, R31.1
unnamed: LED12.C, R36.2
unnamed: LED13.C, R37.2
unnamed: J2.6, R32.1
unnamed: IC2.52 (IOB_34), PAD1.1
unnamed: J2.7, R34.1
unnamed: J2.9, R35.1
unnamed: J2.10, R39.1
unnamed: J2.12, R40.1
unnamed: R2.1, S6.1
unnamed: R5.1, S5.1
unnamed: R7.1, S7.1
unnamed: R22.1, S8.1
unnamed: R24.1, S3.1
unnamed: R47.1, S2.1
unnamed: R49.1, S1.1
unnamed: R51.1, S13.1
unnamed: R53.1, S4.1
unnamed: IC2.58 (IOB_38), PAD2.1
unnamed: IC2.63 (IOB_42_CBSEL0), PAD3.1
PRE_FUSE: FUSE.2, U$2.VBUS1 (VBUS), U$2.VBUS2 (VBUS)
RED: R25.2, R26.2, R27.2, U$1.1
RED_1: IC2.91 (IOR_59), R25.1
RED_2: IC2.95 (IOR_62), R26.1
RED_3: IC2.96 (IOR_63), R27.1
SD_CLK: IC2.32 (IOL_11B), J3.5 (CLK)
VCC: IC6.8 (VCC)
V_SYNC: IC2.97 (IOR_64), U$1.14
V_SYNC_IN: IC2.61 (IOB_40), JP1.3

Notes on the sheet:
NO GND!!
POWER
reverse polarity
protection P-FET
PROGRAMMING
FPGA
KEYBOARD
2 - RED 1 - GREEN 0 - BLUE
ONE BIT / FOUR BIT MODE

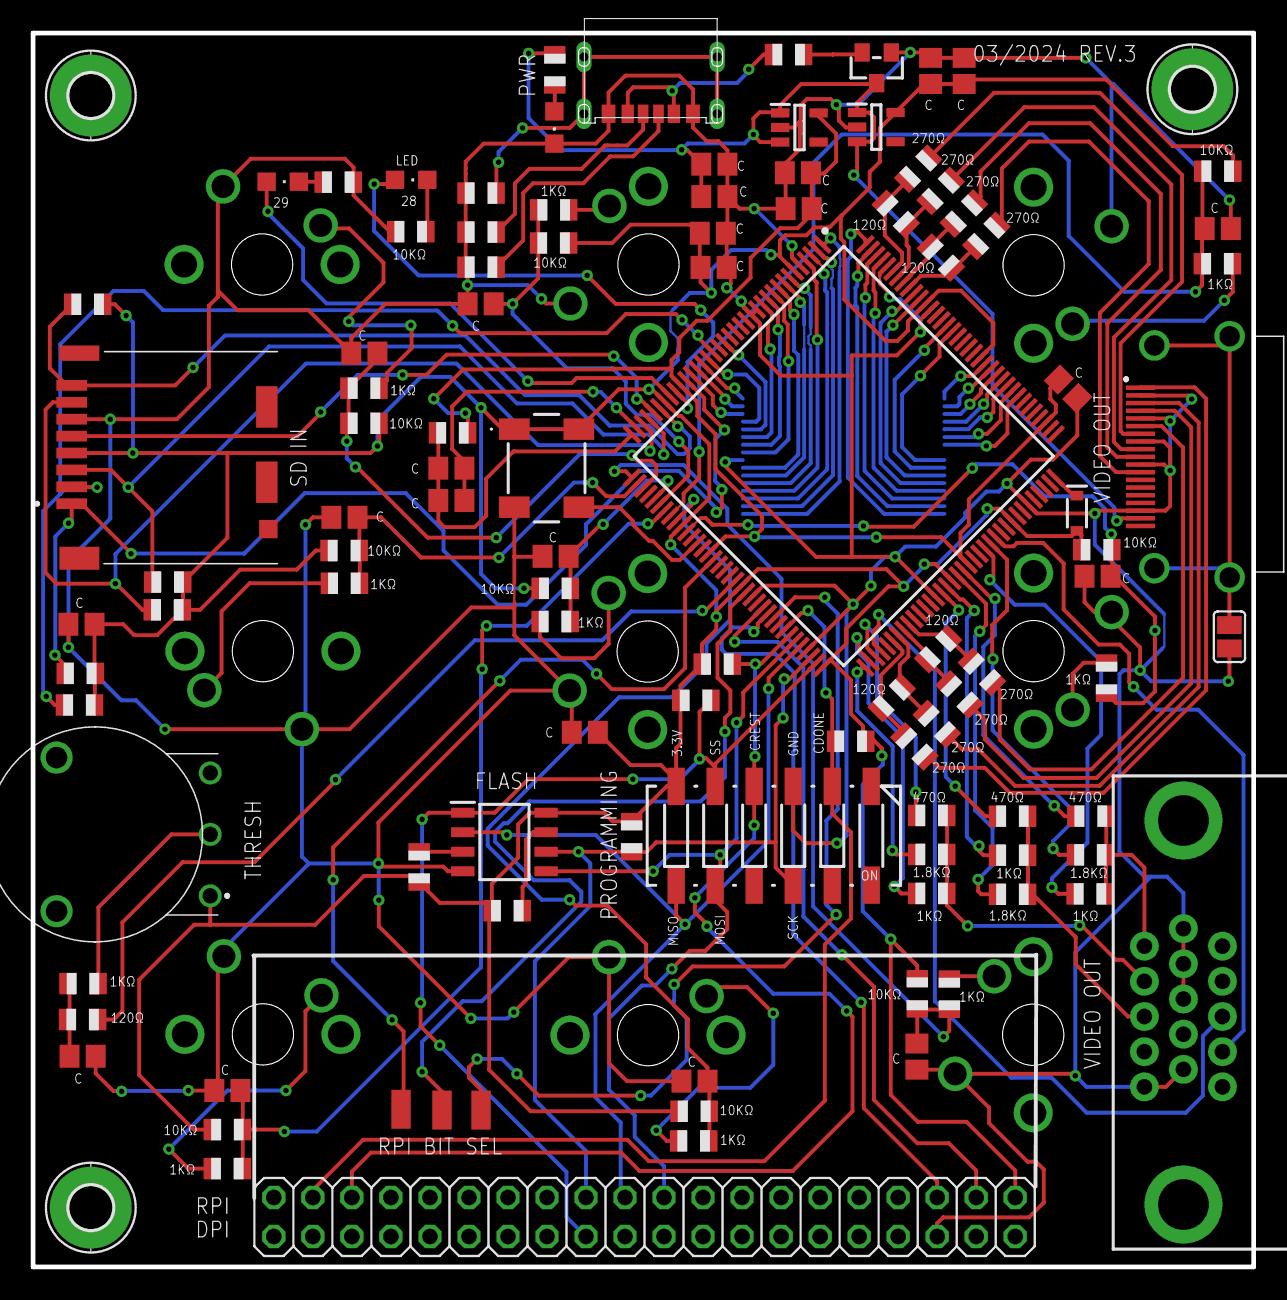
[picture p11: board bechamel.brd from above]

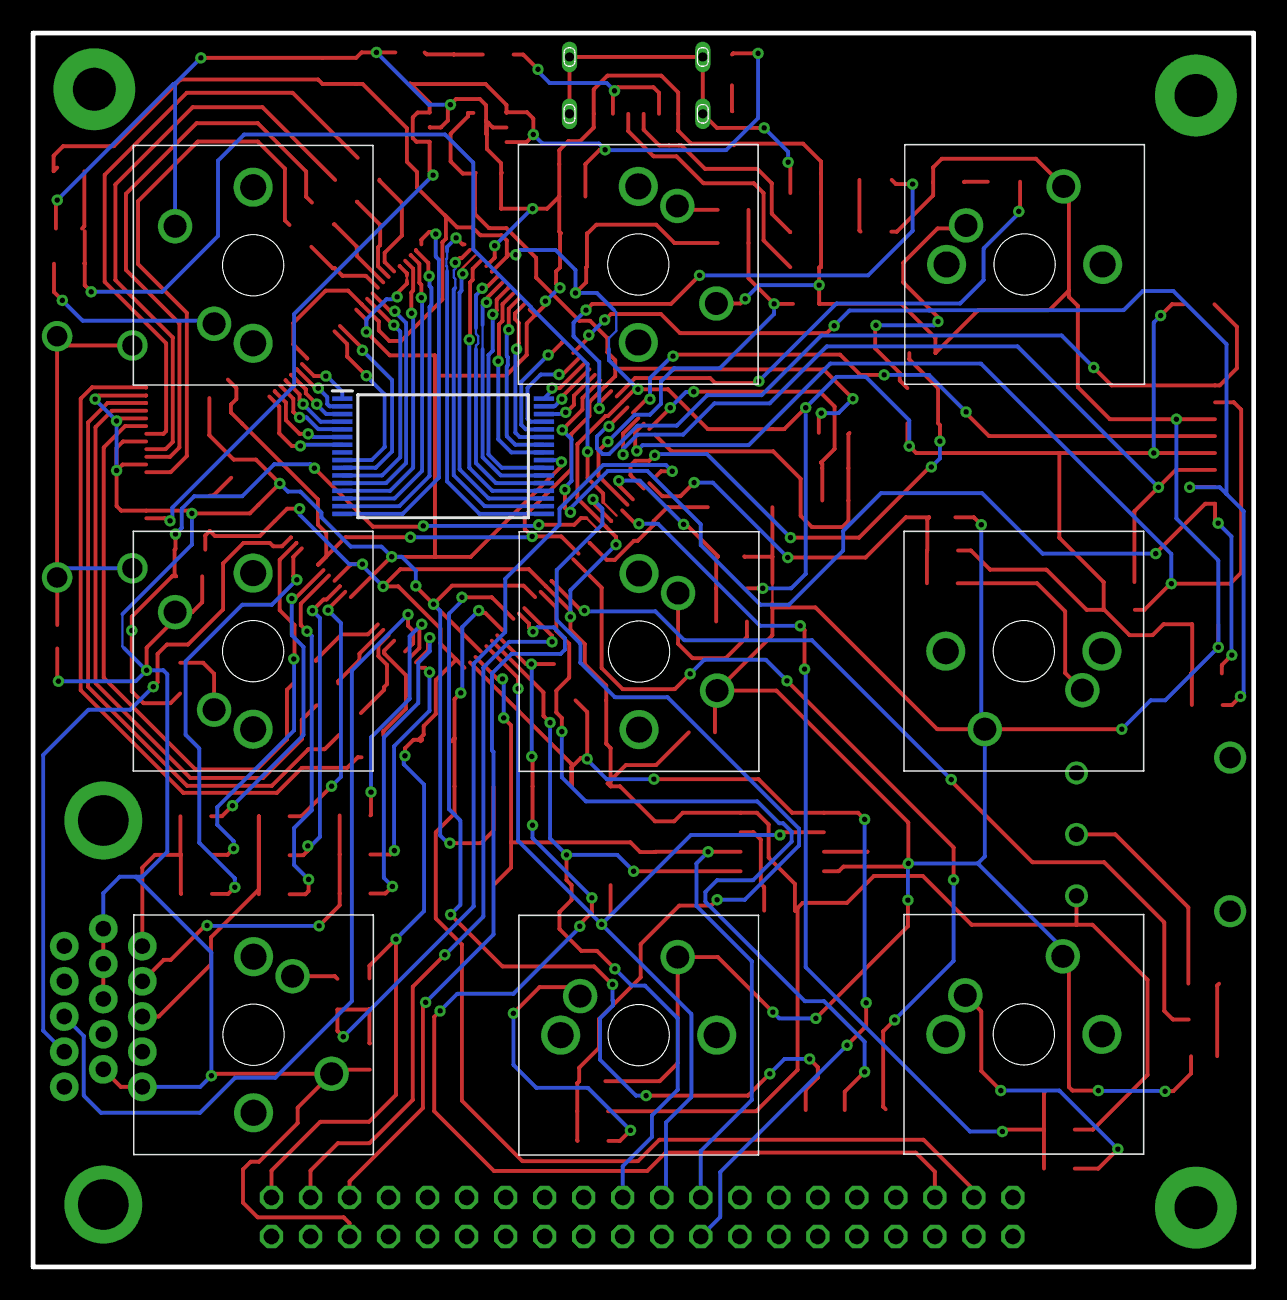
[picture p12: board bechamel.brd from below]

Board: 2 copper layers, 79.5 x 80.3 mm, 117 parts (10 on the bottom side), 119 nets.

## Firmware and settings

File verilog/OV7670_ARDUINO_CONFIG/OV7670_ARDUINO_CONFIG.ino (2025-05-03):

#include <stdint.h>
#include <avr/io.h>
#include <util/twi.h>
#include <util/delay.h>
#include <avr/pgmspace.h>
#define F_CPU 16000000UL
#define vga   0
#define qvga  1
#define qqvga   2
#define yuv422  0
#define rgb565  1
#define bayerRGB  2
#define camAddr_WR  0x42
#define camAddr_RD  0x43
/* Registers */
#define REG_GAIN    0x00  /* Gain lower 8 bits (rest in vref) */
#define REG_BLUE    0x01  /* blue gain */
#define REG_RED       0x02  /* red gain */
#define REG_VREF    0x03  /* Pieces of GAIN, VSTART, VSTOP */
#define REG_COM1    0x04  /* Control 1 */
#define COM1_CCIR656  0x40    /* CCIR656 enable */
#define REG_BAVE    0x05  /* U/B Average level */
#define REG_GbAVE   0x06  /* Y/Gb Average level */
#define REG_AECHH   0x07  /* AEC MS 5 bits */
#define REG_RAVE    0x08  /* V/R Average level */
#define REG_COM2    0x09  /* Control 2 */
#define COM2_SSLEEP         0x10  /* Soft sleep mode */
#define REG_PID           0x0a  /* Product ID MSB */
#define REG_VER           0x0b  /* Product ID LSB */
#define REG_COM3    0x0c  /* Control 3 */
#define COM3_SWAP         0x40  /* Byte swap */
#define COM3_SCALEEN          0x08  /* Enable scaling */
#define COM3_DCWEN          0x04  /* Enable downsamp/crop/window */
#define REG_COM4    0x0d  /* Control 4 */
#define REG_COM5    0x0e  /* All "reserved" */
#define REG_COM6    0x0f  /* Control 6 */
#define REG_AECH    0x10  /* More bits of AEC value */
#define REG_CLKRC   0x11  /* Clocl control */
#define CLK_EXT           0x40  /* Use external clock directly */
#define CLK_SCALE   0x3f  /* Mask for internal clock scale */
#define REG_COM7    0x12  /* Control 7 */ //REG mean address.
#define COM7_RESET          0x80  /* Register reset */
#define COM7_FMT_MASK         0x38
#define COM7_FMT_VGA          0x00
#define COM7_FMT_CIF          0x20  /* CIF format */
#define COM7_FMT_QVGA         0x10  /* QVGA format */
#define COM7_FMT_QCIF         0x08  /* QCIF format */
#define COM7_RGB          0x04  /* bits 0 and 2 - RGB format */
#define COM7_YUV          0x00  /* YUV */
#define COM7_BAYER          0x01  /* Bayer format */
#define COM7_PBAYER         0x05  /* "Processed bayer" */
#define REG_COM8    0x13  /* Control 8 */
#define COM8_FASTAEC          0x80  /* Enable fast AGC/AEC */
#define COM8_AECSTEP          0x40  /* Unlimited AEC step size */
#define COM8_BFILT    0x20  /* Band filter enable */
#define COM8_AGC    0x04  /* Auto gain enable */
#define COM8_AWB    0x02  /* White balance enable */
#define COM8_AEC    0x01  /* Auto exposure enable */
#define REG_COM9    0x14  /* Control 9- gain ceiling */
#define REG_COM10   0x15  /* Control 10 */
#define COM10_HSYNC         0x40  /* HSYNC instead of HREF */
#define COM10_PCLK_HB         0x20  /* Suppress PCLK on horiz blank */
#define COM10_HREF_REV          0x08  /* Reverse HREF */
#define COM10_VS_LEAD         0x04  /* VSYNC on clock leading edge */
#define COM10_VS_NEG          0x02  /* VSYNC negative */
#define COM10_HS_NEG          0x01  /* HSYNC negative */
#define REG_HSTART    0x17  /* Horiz start high bits */
#define REG_HSTOP   0x18  /* Horiz stop high bits */
#define REG_VSTART    0x19  /* Vert start high bits */
#define REG_VSTOP   0x1a  /* Vert stop high bits */
#define REG_PSHFT   0x1b  /* Pixel delay after HREF */
#define REG_MIDH    0x1c  /* Manuf. ID high */
#define REG_MIDL    0x1d  /* Manuf. ID low */
#define REG_MVFP    0x1e  /* Mirror / vflip */
#define MVFP_MIRROR         0x20  /* Mirror image */
#define MVFP_FLIP   0x10  /* Vertical flip */
#define REG_AEW           0x24  /* AGC upper limit */
#define REG_AEB           0x25    /* AGC lower limit */
#define REG_VPT           0x26  /* AGC/AEC fast mode op region */
#define REG_HSYST   0x30  /* HSYNC rising edge delay */
#define REG_HSYEN   0x31  /* HSYNC falling edge delay */
#define REG_HREF    0x32  /* HREF pieces */
#define REG_TSLB    0x3a  /* lots of stuff */
#define TSLB_YLAST    0x04  /* UYVY or VYUY - see com13 */
#define REG_COM11   0x3b  /* Control 11 */
#define COM11_NIGHT         0x80  /* NIght mode enable */
#define COM11_NMFR          0x60  /* Two bit NM frame rate */
#define COM11_HZAUTO          0x10  /* Auto detect 50/60 Hz */
#define COM11_50HZ          0x08  /* Manual 50Hz select */
#define COM11_EXP   0x02
#define REG_COM12   0x3c  /* Control 12 */
#define COM12_HREF          0x80  /* HREF always */
#define REG_COM13   0x3d  /* Control 13 */
#define COM13_GAMMA         0x80  /* Gamma enable */
#define COM13_UVSAT         0x40  /* UV saturation auto adjustment */
#define COM13_UVSWAP          0x01  /* V before U - w/TSLB */
#define REG_COM14   0x3e  /* Control 14 */
#define COM14_DCWEN         0x10  /* DCW/PCLK-scale enable */
#define REG_EDGE    0x3f  /* Edge enhancement factor */
#define REG_COM15   0x40  /* Control 15 */
#define COM15_R10F0         0x00  /* Data range 10 to F0 */
#define COM15_R01FE         0x80  /*      01 to FE */
#define COM15_R00FF         0xc0  /*      00 to FF */
#define COM15_RGB565          0x10  /* RGB565 output */
#define COM15_RGB555          0x30  /* RGB555 output */
#define REG_COM16   0x41  /* Control 16 */
#define COM16_AWBGAIN         0x08  /* AWB gain enable */
#define REG_COM17   0x42  /* Control 17 */
#define COM17_AECWIN          0xc0  /* AEC window - must match COM4 */
#define COM17_CBAR          0x08  /* DSP Color bar */
/*
* This matrix defines how the colors are generated, must be
* tweaked to adjust hue and saturation.
*
* Order: v-red, v-green, v-blue, u-red, u-green, u-blue
* They are nine-bit signed quantities, with the sign bit
* stored in0x58.Sign for v-red is bit 0, and up from there.
*/
#define REG_CMATRIX_BASE  0x4f
#define CMATRIX_LEN           6
#define REG_CMATRIX_SIGN  0x58
#define REG_BRIGHT    0x55  /* Brightness */
#define REG_CONTRAS         0x56  /* Contrast control */
#define REG_GFIX    0x69  /* Fix gain control */
#define REG_REG76   0x76  /* OV's name */
#define R76_BLKPCOR         0x80  /* Black pixel correction enable */
#define R76_WHTPCOR         0x40  /* White pixel correction enable */
#define REG_RGB444          0x8c  /* RGB 444 control */
#define R444_ENABLE         0x02  /* Turn on RGB444, overrides 5x5 */
#define R444_RGBX   0x01  /* Empty nibble at end */
#define REG_HAECC1    0x9f  /* Hist AEC/AGC control 1 */
#define REG_HAECC2    0xa0  /* Hist AEC/AGC control 2 */
#define REG_BD50MAX         0xa5  /* 50hz banding step limit */
#define REG_HAECC3    0xa6  /* Hist AEC/AGC control 3 */
#define REG_HAECC4    0xa7  /* Hist AEC/AGC control 4 */
#define REG_HAECC5    0xa8  /* Hist AEC/AGC control 5 */
#define REG_HAECC6    0xa9  /* Hist AEC/AGC control 6 */
#define REG_HAECC7    0xaa  /* Hist AEC/AGC control 7 */
#define REG_BD60MAX         0xab  /* 60hz banding step limit */
#define REG_GAIN    0x00  /* Gain lower 8 bits (rest in vref) */
#define REG_BLUE    0x01  /* blue gain */
#define REG_RED           0x02  /* red gain */
#define REG_VREF    0x03  /* Pieces of GAIN, VSTART, VSTOP */
#define REG_COM1    0x04  /* Control 1 */
#define COM1_CCIR656          0x40  /* CCIR656 enable */
#define REG_BAVE    0x05  /* U/B Average level */
#define REG_GbAVE   0x06  /* Y/Gb Average level */
#define REG_AECHH   0x07  /* AEC MS 5 bits */
#define REG_RAVE    0x08  /* V/R Average level */
#define REG_COM2    0x09  /* Control 2 */
#define COM2_SSLEEP         0x10  /* Soft sleep mode */
#define REG_PID           0x0a  /* Product ID MSB */
#define REG_VER           0x0b  /* Product ID LSB */
#define REG_COM3    0x0c  /* Control 3 */
#define COM3_SWAP         0x40  /* Byte swap */
#define COM3_SCALEEN          0x08  /* Enable scaling */
#define COM3_DCWEN          0x04  /* Enable downsamp/crop/window */
#define REG_COM4    0x0d  /* Control 4 */
#define REG_COM5    0x0e  /* All "reserved" */
#define REG_COM6    0x0f  /* Control 6 */
#define REG_AECH    0x10  /* More bits of AEC value */
#define REG_CLKRC   0x11  /* Clocl control */
#define CLK_EXT           0x40  /* Use external clock directly */
#define CLK_SCALE   0x3f  /* Mask for internal clock scale */
#define REG_COM7    0x12  /* Control 7 */
#define COM7_RESET          0x80  /* Register reset */
#define COM7_FMT_MASK         0x38
#define COM7_FMT_VGA          0x00
#define COM7_FMT_CIF          0x20  /* CIF format */
#define COM7_FMT_QVGA         0x10  /* QVGA format */
#define COM7_FMT_QCIF         0x08  /* QCIF format */
#define COM7_RGB    0x04  /* bits 0 and 2 - RGB format */
#define COM7_YUV    0x00  /* YUV */
#define COM7_BAYER          0x01  /* Bayer format */
#define COM7_PBAYER         0x05  /* "Processed bayer" */
#define REG_COM8    0x13  /* Control 8 */
#define COM8_FASTAEC          0x80  /* Enable fast AGC/AEC */
#define COM8_AECSTEP          0x40  /* Unlimited AEC step size */
#define COM8_BFILT    0x20  /* Band filter enable */
#define COM8_AGC    0x04  /* Auto gain enable */
#define COM8_AWB    0x02  /* White balance enable */
#define COM8_AEC    0x01  /* Auto exposure enable */
#define REG_COM9    0x14  /* Control 9- gain ceiling */
#define REG_COM10   0x15  /* Control 10 */
#define COM10_HSYNC         0x40  /* HSYNC instead of HREF */
#define COM10_PCLK_HB         0x20  /* Suppress PCLK on horiz blank */
#define COM10_HREF_REV          0x08  /* Reverse HREF */
#define COM10_VS_LEAD           0x04  /* VSYNC on clock leading edge */
#define COM10_VS_NEG          0x02  /* VSYNC negative */
#define COM10_HS_NEG          0x01  /* HSYNC negative */
#define REG_HSTART    0x17  /* Horiz start high bits */
#define REG_HSTOP   0x18  /* Horiz stop high bits */
#define REG_VSTART    0x19  /* Vert start high bits */
#define REG_VSTOP   0x1a  /* Vert stop high bits */
#define REG_PSHFT   0x1b  /* Pixel delay after HREF */
#define REG_MIDH    0x1c  /* Manuf. ID high */
#define REG_MIDL    0x1d  /* Manuf. ID low */
#define REG_MVFP    0x1e  /* Mirror / vflip */
#define MVFP_MIRROR         0x20  /* Mirror image */
#define MVFP_FLIP   0x10  /* Vertical flip */
#define REG_AEW           0x24  /* AGC upper limit */
#define REG_AEB           0x25  /* AGC lower limit */
#define REG_VPT           0x26  /* AGC/AEC fast mode op region */
#define REG_HSYST   0x30  /* HSYNC rising edge delay */
#define REG_HSYEN   0x31  /* HSYNC falling edge delay */
#define REG_HREF    0x32  /* HREF pieces */
#define REG_TSLB    0x3a  /* lots of stuff */
#define TSLB_YLAST    0x04  /* UYVY or VYUY - see com13 */
#define REG_COM11   0x3b  /* Control 11 */
#define COM11_NIGHT         0x80  /* NIght mode enable */
#define COM11_NMFR          0x60  /* Two bit NM frame rate */
#define COM11_HZAUTO          0x10  /* Auto detect 50/60 Hz */
#define COM11_50HZ          0x08  /* Manual 50Hz select */
#define COM11_EXP   0x02
#define REG_COM12   0x3c  /* Control 12 */
#define COM12_HREF          0x80  /* HREF always */
#define REG_COM13   0x3d  /* Control 13 */
#define COM13_GAMMA         0x80  /* Gamma enable */
#define COM13_UVSAT         0x40  /* UV saturation auto adjustment */
#define COM13_UVSWAP          0x01  /* V before U - w/TSLB */
#define REG_COM14   0x3e  /* Control 14 */
#define COM14_DCWEN         0x10  /* DCW/PCLK-scale enable */
#define REG_EDGE    0x3f  /* Edge enhancement factor */
#define REG_COM15   0x40  /* Control 15 */
#define COM15_R10F0         0x00  /* Data range 10 to F0 */
#define COM15_R01FE         0x80  /*      01 to FE */
#define COM15_R00FF         0xc0  /*      00 to FF */
#define COM15_RGB565          0x10  /* RGB565 output */
#define COM15_RGB555          0x30  /* RGB555 output */
#define REG_COM16   0x41  /* Control 16 */
#define COM16_AWBGAIN         0x08  /* AWB gain enable */
#define REG_COM17   0x42  /* Control 17 */
#define COM17_AECWIN          0xc0  /* AEC window - must match COM4 */
#define COM17_CBAR          0x08  /* DSP Color bar */
#define CMATRIX_LEN             6
#define REG_BRIGHT    0x55  /* Brightness */
#define REG_REG76   0x76  /* OV's name */
#define R76_BLKPCOR         0x80  /* Black pixel correction enable */
#define R76_WHTPCOR         0x40  /* White pixel correction enable */
#define REG_RGB444          0x8c  /* RGB 444 control */
#define R444_ENABLE         0x02  /* Turn on RGB444, overrides 5x5 */
#define R444_RGBX   0x01  /* Empty nibble at end */
#define REG_HAECC1    0x9f  /* Hist AEC/AGC control 1 */
#define REG_HAECC2    0xa0  /* Hist AEC/AGC control 2 */
#define REG_BD50MAX         0xa5  /* 50hz banding step limit */
#define REG_HAECC3    0xa6  /* Hist AEC/AGC control 3 */
#define REG_HAECC4    0xa7  /* Hist AEC/AGC control 4 */
#define REG_HAECC5    0xa8  /* Hist AEC/AGC control 5 */
#define REG_HAECC6    0xa9  /* Hist AEC/AGC control 6 */
#define REG_HAECC7    0xaa  /* Hist AEC/AGC control 7 */
#define REG_BD60MAX         0xab  /* 60hz banding step limit */
#define MTX1            0x4f  /* Matrix Coefficient 1 */
#define MTX2            0x50  /* Matrix Coefficient 2 */
#define MTX3            0x51  /* Matrix Coefficient 3 */
#define MTX4            0x52  /* Matrix Coefficient 4 */
#define MTX5            0x53  /* Matrix Coefficient 5 */
#define MTX6            0x54  /* Matrix Coefficient 6 */
#define REG_CONTRAS         0x56  /* Contrast control */
#define MTXS            0x58  /* Matrix Coefficient Sign */
#define AWBC7           0x59  /* AWB Control 7 */
#define AWBC8           0x5a  /* AWB Control 8 */
#define AWBC9           0x5b  /* AWB Control 9 */
#define AWBC10            0x5c  /* AWB Control 10 */
#define AWBC11            0x5d  /* AWB Control 11 */
#define AWBC12            0x5e  /* AWB Control 12 */
#define REG_GFI           0x69  /* Fix gain control */
#define GGAIN           0x6a  /* G Channel AWB Gain */
#define DBLV            0x6b  
#define AWBCTR3           0x6c  /* AWB Control 3 */
#define AWBCTR2           0x6d  /* AWB Control 2 */
#define AWBCTR1           0x6e  /* AWB Control 1 */
#define AWBCTR0           0x6f  /* AWB Control 0 */
struct regval_list{
  uint8_t reg_num;
  uint16_t value;
};
const struct regval_list qvga_ov7670[] PROGMEM = {
  { REG_HSTART, 0x16 },
  { REG_HSTOP, 0x04 },
  { REG_HREF, 0xa4 },
  { REG_VSTART, 0x02 },
  { REG_VSTOP, 0x7a },
  { REG_VREF, 0x0a },
  { 0xff, 0xff }, /* END MARKER */
};
const struct regval_list yuv422_ov7670[] PROGMEM = {
  { REG_COM9, 0x6A }, /* 128x gain ceiling; 0x8 is reserved bit */
  { 0x4f, 0x80 },   /* "matrix coefficient 1" */
  { 0x50, 0x80 },   /* "matrix coefficient 2" */
  { 0x51, 0 },    /* vb */
  { 0x52, 0x22 },   /* "matrix coefficient 4" */
  { 0x53, 0x5e },   /* "matrix coefficient 5" */
  { 0x54, 0x80 },   /* "matrix coefficient 6" */
  { REG_COM13, COM13_UVSAT },
  { 0xff, 0xff },   /* END MARKER */
};
const struct regval_list ov7670_default_regs[] PROGMEM = {//from the linux driver
  { REG_COM7, COM7_RESET },
  { REG_TSLB, 0x04 }, /* OV */
  { REG_COM7, 0 },  /* VGA */
  /*
  * Set the hardware window.  These values from OV don't entirely
  * make sense - hstop is less than hstart.  But they work...
  */
  { REG_HSTART, 0x13 }, { REG_HSTOP, 0x01 },
  { REG_HREF, 0xb6 }, { REG_VSTART, 0x02 },
  { REG_VSTOP, 0x7a }, { REG_VREF, 0x0a },
  { REG_COM3, 0 }, { REG_COM14, 0 },
  /* Mystery scaling numbers */
  { 0x70, 0x3a }, { 0x71, 0x35 },
  { 0x72, 0x11 }, { 0x73, 0xf0 },
  { 0xa2,/* 0x02 changed to 1*/1 }, { REG_COM10, 0x0 },
  /* Gamma curve values */
  { 0x7a, 0x20 }, { 0x7b, 0x10 },
  { 0x7c, 0x1e }, { 0x7d, 0x35 },
  { 0x7e, 0x5a }, { 0x7f, 0x69 },
  { 0x80, 0x76 }, { 0x81, 0x80 },
  { 0x82, 0x88 }, { 0x83, 0x8f },
  { 0x84, 0x96 }, { 0x85, 0xa3 },
  { 0x86, 0xaf }, { 0x87, 0xc4 },
  { 0x88, 0xd7 }, { 0x89, 0xe8 },
  /* AGC and AEC parameters.  Note we start by disabling those features,
  then turn them only after tweaking the values. */
  { REG_COM8, COM8_FASTAEC | COM8_AECSTEP },
  { REG_GAIN, 0 }, { REG_AECH, 0 },
  { REG_COM4, 0x40 }, /* magic reserved bit */
  { REG_COM9, 0x18 }, /* 4x gain + magic rsvd bit */
  { REG_BD50MAX, 0x05 }, { REG_BD60MAX, 0x07 },
  { REG_AEW, 0x95 }, { REG_AEB, 0x33 },
  { REG_VPT, 0xe3 }, { REG_HAECC1, 0x78 },
  { REG_HAECC2, 0x68 }, { 0xa1, 0x03 }, /* magic */
  { REG_HAECC3, 0xd8 }, { REG_HAECC4, 0xd8 },
  { REG_HAECC5, 0xf0 }, { REG_HAECC6, 0x90 },
  { REG_HAECC7, 0x94 },
  { REG_COM8, COM8_FASTAEC | COM8_AECSTEP | COM8_AGC | COM8_AEC },
  { 0x30, 0 }, { 0x31, 0 },//disable some delays
  /* Almost all of these are magic "reserved" values.  */
  { REG_COM5, 0x61 }, { REG_COM6, 0x4b },
  { 0x16, 0x02 }, { REG_MVFP, 0x07 },
  { 0x21, 0x02 }, { 0x22, 0x91 },
  { 0x29, 0x07 }, { 0x33, 0x0b },
  { 0x35, 0x0b }, { 0x37, 0x1d },
  { 0x38, 0x71 }, { 0x39, 0x2a },
  { REG_COM12, 0x78 }, { 0x4d, 0x40 },
  { 0x4e, 0x20 }, { REG_GFIX, 0 },
  /*{0x6b, 0x4a},*/{ 0x74, 0x10 },
  { 0x8d, 0x4f }, { 0x8e, 0 },
  { 0x8f, 0 }, { 0x90, 0 },
  { 0x91, 0 }, { 0x96, 0 },
  { 0x9a, 0 }, { 0xb0, 0x84 },
  { 0xb1, 0x0c }, { 0xb2, 0x0e },
  { 0xb3, 0x82 }, { 0xb8, 0x0a },
  /* More reserved magic, some of which tweaks white balance */
  { 0x43, 0x0a }, { 0x44, 0xf0 },
  { 0x45, 0x34 }, { 0x46, 0x58 },
  { 0x47, 0x28 }, { 0x48, 0x3a },
  { 0x59, 0x88 }, { 0x5a, 0x88 },
  { 0x5b, 0x44 }, { 0x5c, 0x67 },
  { 0x5d, 0x49 }, { 0x5e, 0x0e },
  { 0x6c, 0x0a }, { 0x6d, 0x55 },
  { 0x6e, 0x11 }, { 0x6f, 0x9e }, /* it was 0x9F "9e for advance AWB" */
  { 0x6a, 0x40 }, { REG_BLUE, 0x40 },
  { REG_RED, 0x60 },
  { REG_COM8, COM8_FASTAEC | COM8_AECSTEP | COM8_AGC | COM8_AEC | COM8_AWB },
  /* Matrix coefficients */
  { 0x4f, 0x80 }, { 0x50, 0x80 },
  { 0x51, 0 },    { 0x52, 0x22 },
  { 0x53, 0x5e }, { 0x54, 0x80 },
  { 0x58, 0x9e },
  { REG_COM16, COM16_AWBGAIN }, { REG_EDGE, 0 },
  { 0x75, 0x05 }, { REG_REG76, 0xe1 },
  { 0x4c, 0 },     { 0x77, 0x01 },
  { REG_COM13, /*0xc3*/0x48 }, { 0x4b, 0x09 },
  { 0xc9, 0x60 },   /*{REG_COM16, 0x38},*/
  { 0x56, 0x40 },
  { 0x34, 0x11 }, { REG_COM11, COM11_EXP | COM11_HZAUTO },
  { 0xa4, 0x82/*Was 0x88*/ }, { 0x96, 0 },
  { 0x97, 0x30 }, { 0x98, 0x20 },
  { 0x99, 0x30 }, { 0x9a, 0x84 },
  { 0x9b, 0x29 }, { 0x9c, 0x03 },
  { 0x9d, 0x4c }, { 0x9e, 0x3f },
  { 0x78, 0x04 },
  /* Extra-weird stuff.  Some sort of multiplexor register */
  { 0x79, 0x01 }, { 0xc8, 0xf0 },
  { 0x79, 0x0f }, { 0xc8, 0x00 },
  { 0x79, 0x10 }, { 0xc8, 0x7e },
  { 0x79, 0x0a }, { 0xc8, 0x80 },
  { 0x79, 0x0b }, { 0xc8, 0x01 },
  { 0x79, 0x0c }, { 0xc8, 0x0f },
  { 0x79, 0x0d }, { 0xc8, 0x20 },
  { 0x79, 0x09 }, { 0xc8, 0x80 },
  { 0x79, 0x02 }, { 0xc8, 0xc0 },
  { 0x79, 0x03 }, { 0xc8, 0x40 },
  { 0x79, 0x05 }, { 0xc8, 0x30 },
  { 0x79, 0x26 },
  { 0xff, 0xff }, /* END MARKER */
};
void error_led(void){
  DDRB |= 32;//make sure led is output
  while (1){//wait for reset
    PORTB ^= 32;// toggle led
    _delay_ms(100);
  }
}
void twiStart(void){
  TWCR = _BV(TWINT) | _BV(TWSTA) | _BV(TWEN);//send start
  while (!(TWCR & (1 << TWINT)));//wait for start to be transmitted
  if ((TWSR & 0xF8) != TW_START)
    error_led();
}
void twiWriteByte(uint8_t DATA, uint8_t type){
  TWDR = DATA;
  TWCR = _BV(TWINT) | _BV(TWEN);
  while (!(TWCR & (1 << TWINT))) {}
  if ((TWSR & 0xF8) != type)
    error_led();
}
void twiAddr(uint8_t addr, uint8_t typeTWI){
  TWDR = addr;//send address
  TWCR = _BV(TWINT) | _BV(TWEN);    /* clear interrupt to start transmission */
  while ((TWCR & _BV(TWINT)) == 0); /* wait for transmission */
  if ((TWSR & 0xF8) != typeTWI)
    error_led();
}
void writeReg(uint8_t reg, uint8_t dat){
  //send start condition
  twiStart();
  twiAddr(camAddr_WR, TW_MT_SLA_ACK);
  twiWriteByte(reg, TW_MT_DATA_ACK);
  twiWriteByte(dat, TW_MT_DATA_ACK);
  TWCR = (1 << TWINT) | (1 << TWEN) | (1 << TWSTO);//send stop
  _delay_ms(1);
}
static uint8_t twiRd(uint8_t nack){
  if (nack){
    TWCR = _BV(TWINT) | _BV(TWEN);
    while ((TWCR & _BV(TWINT)) == 0); /* wait for transmission */
    if ((TWSR & 0xF8) != TW_MR_DATA_NACK)
      error_led();
    return TWDR;
  }
  else{
    TWCR = _BV(TWINT) | _BV(TWEN) | _BV(TWEA);
    while ((TWCR & _BV(TWINT)) == 0); /* wait for transmission */
    if ((TWSR & 0xF8) != TW_MR_DATA_ACK)
      error_led();
    return TWDR;
  }
}
uint8_t rdReg(uint8_t reg){
  uint8_t dat;
  twiStart();
  twiAddr(camAddr_WR, TW_MT_SLA_ACK);
  twiWriteByte(reg, TW_MT_DATA_ACK);
  TWCR = (1 << TWINT) | (1 << TWEN) | (1 << TWSTO);//send stop
  _delay_ms(1);
  twiStart();
  twiAddr(camAddr_RD, TW_MR_SLA_ACK);
  dat = twiRd(1);
  TWCR = (1 << TWINT) | (1 << TWEN) | (1 << TWSTO);//send stop
  _delay_ms(1);
  return dat;
}
void wrSensorRegs8_8(const struct regval_list reglist[]){
  uint8_t reg_addr, reg_val;
  const struct regval_list *next = reglist;
  while ((reg_addr != 0xff) | (reg_val != 0xff)){
    reg_addr = pgm_read_byte(&next->reg_num);
    reg_val = pgm_read_byte(&next->value);
   writeReg(reg_addr, reg_val);
    next++;
  }
}
void setColor(void){
  //wrSensorRegs8_8(yuv422_ov7670);
  wrSensorRegs8_8(qvga_ov7670);
}
void setResolution(void){
 writeReg(REG_COM3, 4); // REG_COM3 enable scaling
  wrSensorRegs8_8(qvga_ov7670);
}
void camInit(void){
 writeReg(0x12, 0x80);
  _delay_ms(100);
  wrSensorRegs8_8(ov7670_default_regs);
 writeReg(REG_COM10, 32);//PCLK does not toggle on HBLANK.
}
void arduinoUnoInut(void) {
  cli();//disable interrupts
    /* Setup the 8mhz PWM clock
  * This will be on pin 11*/
  DDRB |= (1 << 3);//pin 11
  ASSR &= ~(_BV(EXCLK) | _BV(AS2));
  TCCR2A = (1 << COM2A0) | (1 << WGM21) | (1 << WGM20);
  TCCR2B = (1 << WGM22) | (1 << CS20);
  OCR2A = 1;//(F_CPU)/(2*(X+1))
  DDRC &= ~15;//low d0-d3 camera
  DDRD &= ~252;//d7-d4 and interrupt pins
  _delay_ms(3000);
    //set up twi for 100khz
  TWSR &= ~3;//disable prescaler for TWI
  TWBR = 72;//set to 100khz
    //enable serial
  UBRR0H = 0;
  UBRR0L = 7;//0 = 2M baud rate. 1 = 1M baud. 3 = 0.5M. 7 = 250k 207 is 9600 baud rate.
  UCSR0A |= 2;//double speed aysnc
  UCSR0B = (1 << RXEN0) | (1 << TXEN0);//Enable receiver and transmitter
  UCSR0C = 6;//async 1 stop bit 8bit char no parity bits
}
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
void loop(){
 // captureImg(320, 240);
}

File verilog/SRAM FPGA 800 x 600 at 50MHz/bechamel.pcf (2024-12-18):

set_io hdmi_p[0] 139 -io_std SB_LVCMOS
set_io hdmi_p[2] 78 -io_std SB_LVCMOS
set_io hdmi_p[1] 80 -io_std SB_LVCMOS
set_io hdmi_p[3] 137 -io_std SB_LVCMOS

set_io hdmi_n[0] 138 -io_std SB_LVCMOS
set_io hdmi_n[2] 79 -io_std SB_LVCMOS
set_io hdmi_n[1] 81 -io_std SB_LVCMOS
set_io hdmi_n[3] 136 -io_std SB_LVCMOS

set_io key[0] 37
set_io key[1] 38
set_io key[2] 39
set_io key[3] 41
set_io key[4] 42
set_io key[5] 43
set_io key[6] 44
set_io key[7] 45
set_io rec 47

set_io SCK 32
set_io CMD 33

set_io LED1 29
set_io LED5 28

set_io reset 66

set_io clk_in 49

set_io b_in 63

set_io rpi_pixel_clock 61
set_io rpi_hsync 52
set_io rpi_vsync 58
set_io rpi_DEN 62

set_io r_out[0] 91 //for vga
set_io r_out[1] 95 //for vga
set_io r_out[2] 96 //for vga

set_io b_out[0] 87 //for vga
set_io b_out[1] 88 //for vga
set_io b_out[2] 90 //for vga

set_io g_out[0] 75 //for vga
set_io g_out[1] 74 //for vga
set_io g_out[2] 73 //for vga

set_io v_sync 97 //for vga
set_io h_sync 76 //for vga

set_io io[0] 7
set_io io[1] 8
set_io io[2] 9
set_io io[3] 10
set_io io[4] 11
set_io io[5] 12
set_io io[6] 19
set_io io[7] 22

set_io addr[0] 4
set_io addr[1] 3
set_io addr[2] 2
set_io addr[3] 1
set_io addr[4] 144
set_io addr[5] 143
set_io addr[6] 142
set_io addr[7] 141
set_io addr[8] 120
set_io addr[9] 121
set_io addr[10] 24
set_io addr[11] 122
set_io addr[12] 135
set_io addr[13] 119
set_io addr[14] 134
set_io addr[15] 116
set_io addr[16] 129
set_io addr[17] 128


set_io cs 25
set_io oe 23
set_io we 118

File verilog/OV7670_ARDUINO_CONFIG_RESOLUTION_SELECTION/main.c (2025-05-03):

#define F_CPU 16000000UL
#include <stdint.h>
#include <avr/io.h>
#include <avr/interrupt.h>
#include <util/twi.h>
#include <util/delay.h>
#include <avr/pgmspace.h>
#include "ov7670.h"
/* Configuration: this lets you easily change between different resolutions
 * You must only uncomment one
 * no more no less*/
#define useVga
//#define useQvga
//#define useQqvga

static inline void serialWrB(uint8_t dat){
	while(!( UCSR0A & (1<<UDRE0)));//wait for byte to transmit
	UDR0=dat;
	while(!( UCSR0A & (1<<UDRE0)));//wait for byte to transmit
}
static void StringPgm(const char * str){
	do{
		serialWrB(pgm_read_byte_near(str));
	}while(pgm_read_byte_near(++str));
}
static void captureImg(uint16_t wg,uint16_t hg){
	uint16_t lg2;
#ifdef useQvga
	uint8_t buf[640];
#elif defined(useQqvga)
	uint8_t buf[320];
#endif
	StringPgm(PSTR("RDY"));
	//Wait for vsync it is on pin 3 (counting from 0) portD
	while(!(PIND&8));//wait for high
	while((PIND&8));//wait for low
#ifdef useVga
	while(hg--){
		lg2=wg;
		while(lg2--){
			while((PIND&4));//wait for low
			UDR0=(PINC&15)|(PIND&240);
			while(!(PIND&4));//wait for high
		}
	}
#elif defined(useQvga)
	/*We send half of the line while reading then half later */
	while(hg--){
		uint8_t*b=buf,*b2=buf;
		lg2=wg/2;
		while(lg2--){
			while((PIND&4));//wait for low
			*b++=(PINC&15)|(PIND&240);
			while(!(PIND&4));//wait for high
			while((PIND&4));//wait for low
			*b++=(PINC&15)|(PIND&240);
			UDR0=*b2++;
			while(!(PIND&4));//wait for high
		}
		/* Finish sending the remainder during blanking */
		lg2=wg/2;
		while(!( UCSR0A & (1<<UDRE0)));//wait for byte to transmit
		while(lg2--){
			UDR0=*b2++;
			while(!( UCSR0A & (1<<UDRE0)));//wait for byte to transmit
		}
	}
#else
	/* This code is very similar to qvga sending code except we have even more blanking time to take advantage of */
	while(hg--){
		uint8_t*b=buf,*b2=buf;
		lg2=wg/5;
		while(lg2--){
			while((PIND&4));//wait for low
			*b++=(PINC&15)|(PIND&240);
			while(!(PIND&4));//wait for high
			while((PIND&4));//wait for low
			*b++=(PINC&15)|(PIND&240);
			while(!(PIND&4));//wait for high
			while((PIND&4));//wait for low
			*b++=(PINC&15)|(PIND&240);
			while(!(PIND&4));//wait for high
			while((PIND&4));//wait for low
			*b++=(PINC&15)|(PIND&240);
			while(!(PIND&4));//wait for high
			while((PIND&4));//wait for low
			*b++=(PINC&15)|(PIND&240);
			UDR0=*b2++;
			while(!(PIND&4));//wait for high
		}
		/* Finish sending the remainder during blanking */
		lg2=320-(wg/5);
		while(!( UCSR0A & (1<<UDRE0)));//wait for byte to transmit
		while(lg2--){
			UDR0=*b2++;
			while(!( UCSR0A & (1<<UDRE0)));//wait for byte to transmit
		}
	}
#endif
}
int main(void){
	cli();//disable interrupts
	/* Setup the 8mhz PWM clock 
	 * This will be on pin 11*/
	DDRB|=(1<<3);//pin 11
	ASSR &= ~(_BV(EXCLK) | _BV(AS2));
	TCCR2A=(1<<COM2A0)|(1<<WGM21)|(1<<WGM20);
	TCCR2B=(1<<WGM22)|(1<<CS20);
	OCR2A=2;//(F_CPU)/(2*(X+1))
	DDRC&=~15;//low d0-d3 camera
	DDRD&=~252;//d7-d4 and interrupt pins
	_delay_ms(3000);
	//set up twi for 100khz
	TWSR&=~3;//disable prescaler for TWI
	TWBR=72;//set to 100khz
	//enable serial
	//UBRR0H=0;
	//UBRR0L=1;//0 = 2M baud rate. 1 = 1M baud. 3 = 0.5M. 7 = 250k 207 is 9600 baud rate.
	//UCSR0A|=2;//double speed aysnc
	//UCSR0B = (1<<RXEN0)|(1<<TXEN0);//Enable receiver and transmitter
	//UCSR0C=6;//async 1 stop bit 8bit char no parity bits
	camInit();
#ifdef useVga
	setRes(VGA);
	setColorSpace(BAYER_RGB);
	wrReg(0x11,25);
#elif defined(useQvga)
	setRes(QVGA);
	setColorSpace(YUV422);
	wrReg(0x11,12);
#else
	setRes(QQVGA);
	setColorSpace(YUV422);
	wrReg(0x11,3);
#endif
	/* If you are not sure what value to use here for the divider (register 0x11)
	 * Values I have found to work raw vga 25 qqvga yuv422 12 qvga yuv422 21
	 * run the commented out test below and pick the smallest value that gets a correct image */
	while (1){
		/* captureImg operates in bytes not pixels in some cases pixels are two bytes per pixel
		 * So for the width (if you were reading 640x480) you would put 1280 if you are reading yuv422 or rgb565 */
		/*uint8_t x=63;//Uncomment this block to test divider settings note the other line you need to uncomment
		  do{
		  wrReg(0x11,x);
		  _delay_ms(1000);*/
#ifdef useVga
		captureImg(640,480);
#elif defined(useQvga)
		captureImg(320*2,240);
#else
		captureImg(160*2,120);
#endif
		//}while(--x);//Uncomment this line to test divider settings
	}
}

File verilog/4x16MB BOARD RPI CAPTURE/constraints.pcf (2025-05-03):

set_io v_sync 87
set_io h_sync 88
set_io clk_in 64
set_io reset 66
set_io io[0] 1
set_io io[1] 2
set_io io[2] 3
set_io io[3] 4
set_io io[4] 122
set_io io[5] 121
set_io io[6] 120
set_io io[7] 119
set_io addr[0] 138
set_io addr[1] 139
set_io addr[2] 141
set_io addr[3] 142
set_io addr[4] 143
set_io addr[5] 8
set_io addr[6] 9
set_io addr[7] 10
set_io addr[8] 11
set_io addr[9] 12
set_io addr[10] 136
set_io addr[11] 135
set_io addr[12] 134
set_io addr[13] 129
set_io addr[14] 128
set_io addr[15] 117
set_io addr[16] 116
set_io addr[17] 115
set_io addr[18] 114
set_io addr[19] 137
set_io addr[20] 113
set_io cs_0 144
set_io cs_1 71
set_io we_0 7
set_io we_1 50
set_io rec 62
set_io r_in[0] 107
set_io r_in[1] 106
set_io r_in[2] 105
set_io r_in[3] 104
set_io g_in[0] 97
set_io g_in[1] 96
set_io g_in[2] 95
set_io g_in[3] 112
set_io b_in[0] 102
set_io b_in[1] 101
set_io b_in[2] 99
set_io b_in[3] 98
set_io r_out[0] 81
set_io r_out[1] 80
set_io r_out[2] 79
set_io r_out[3] 78
set_io g_out[0] 94
set_io g_out[1] 93
set_io g_out[2] 91
set_io g_out[3] 90
set_io b_out[0] 76
set_io b_out[1] 75
set_io b_out[2] 74
set_io b_out[3] 73

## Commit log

2024-01-24 schematic and board
    [preparedinstruments_0_bechemel_v10 # KEYPAD.brd, preparedinstruments_0_bechemel_v10 # KEYPAD.sch, preparedinstruments_0_bechemel_v11 #MOTHERBOARD.brd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]
2024-01-26 Finished boards and schematics
    [preparedinstruments_0_bechemel_v12 # KEYPAD.brd, preparedinstruments_0_bechemel_v12 # KEYPAD.sch, preparedinstruments_0_bechemel_v12 #MOTHERBOARD.brd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]

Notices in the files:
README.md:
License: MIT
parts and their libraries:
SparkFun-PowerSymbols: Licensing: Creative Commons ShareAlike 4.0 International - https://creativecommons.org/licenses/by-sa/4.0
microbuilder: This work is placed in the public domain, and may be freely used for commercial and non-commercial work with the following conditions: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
